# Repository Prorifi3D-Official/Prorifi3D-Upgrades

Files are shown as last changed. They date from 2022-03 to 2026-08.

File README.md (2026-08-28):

# Prorifi3D 
## Table of Content
### [For Slicer Profiles](https://github.com/Prorifi3D-Official/Prorifi3D-Upgrades/tree/main/Original%20i3%20series%20Upgrade%20Kits/Slicer%20Profile)
### [For Dual Belt Upgrade for Original i3 in Stage 1](https://github.com/Prorifi3D-Official/Prorifi3D-Upgrades/tree/main/Original%20i3%20series%20Upgrade%20Kits/Stage%201%20Upgrade/Dual%20Belt)
### [For Frame Upgrade for Original i3 in Stage 2](https://github.com/Prorifi3D-Official/Prorifi3D-Upgrades/tree/main/Original%20i3%20series%20Upgrade%20Kits/Stage%202%20Upgrade/Frame)
### [For Dual Belt Upgrade for Bear i3](https://github.com/Prorifi3D-Official/Prorifi3D-Upgrades/tree/main/Original%20i3%20series%20Upgrade%20Kits/Stage%201%20Upgrade/For%20Bear%20i3)
### [For MINI/MINI+ Upgrade](https://github.com/Prorifi3D-Official/Prorifi3D-Upgrades/tree/main/Original%20MINI%20series%20Upgrade%20Kits/MINI%20Upgrade/Dual%20Belt)
### [For the Printer Test Bench Guide](docs/Test_Bench_Guide.md)

## To find the latest Guide, visit our Knowledge Base:https://prorifi3d-knowledge-base.readthedocs.io/en/latest/

#### Our Official web site:https://prorifi3d.com/

#### Product page:https://prorifi3d.com/collections/upgrade-kit

#### Technical details about MRR:https://prorifi3d.com/pages/technical-details

#### Our YouTube Channel:https://www.youtube.com/channel/UCRQNWRVH8KuHBi94MY16joQ/featured

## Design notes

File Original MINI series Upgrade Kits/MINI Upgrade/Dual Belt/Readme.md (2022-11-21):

# Print Settings

### Recommended infill: >= 30%
### Recommended layer height: 0.2mm
### Recommended Material: PETG
### For other settings use: PrusaSlicer's default PETG 0.2mm presets
### For printed parts and multi-color parts, you can use the .3mf files to print them or as a reference, we recommend you use the water blue color first and then black. You can also use your own preferred color.

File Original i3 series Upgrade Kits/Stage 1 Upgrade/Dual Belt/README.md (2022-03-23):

# Print Settings

### Recommended infill: >= 30%
### Recommended layer hieght: 0.2mm
### Recommended Material: PETG
### For other settings use: PrusaSlicer's default PETG 0.2mm presets

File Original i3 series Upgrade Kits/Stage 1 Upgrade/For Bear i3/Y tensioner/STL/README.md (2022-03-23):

# Difference in Bear version:

### Y-Belt-Idler-A.stl -> Bear-y-idler-mount.stl
### Y-Belt-Idler-B.stl -> y_idler_tensioner.stl

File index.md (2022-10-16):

# HomePage
-------------------------------------

#This is the Prorifi3D Knowledge Base where you can find all technical details and information about our products and theory.

To get the Upgrade kits:

- [Upgrade Kit for Original i3 MK3/MK3S/MK3S+](https://prorifi3d.com/collections/upgrade-kit/products/kit)

- [Upgrade Kit for Original MINI/MINI+](https://prorifi3d.com/collections/upgrade-kit/products/mini)

- [Motor Development Kit](https://prorifi3d.com/collections/upgrade-kit/products/prorifi3d-motor-development-kit)

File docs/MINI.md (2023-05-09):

---
hide: navigation
---

# MINI:Motor Upgrades

## 1. Preparation and disassembly

### 1.0 Introduction

<span style="color:red"> **READ THE INSTRUCTION BEFORE UPGRADE!!** </span>  

- Prorifi3D Upgrade Kit for Original MINI/MINI+ is fully compatible with the Original i3 MINI series firmware and hardware.  

- Since you are upgrading an existing Original MINI or clone, you will have to replace X and Y motors, if you have experience in assembling Original MINI, that’s perfect! if not, don’t worry, follow this guide, and everything will be smooth and fine.  

- Disclaimer: We share these guides to make your experience as smooth as possible. However, you are responsible for your upgrade, assembly, and any damage you cause to your hardware.  

### 1.1 Check before Upgrade

Make sure you have the following tools and things available in the following 15 minutes:  

1. Your Original MINI 

2. 2.5mm, 2mm, and 1.5mm hex keys for disassembly, you can find one 1.5mm hex key in our accessory pack if you do not have one.  

3. A cutting tool for cutting zip ties  

4. Your Prorifi3D motor upgrade kit  

5. A small box for keeping the screws  

6. Printed parts for the new Dual belt Plus (From [Our GitHub](https://github.com/Prorifi3D-Official/Prorifi3D-Upgrades/tree/main/Original%20MINI%20series%20Upgrade%20Kits/MINI%20Upgrade)  Note that you will have to change the front and rear plate.

7. Open the Original Prusa MINI kit assembly Guide for reference([https://help.prusa3d.com/guide/1-introduction_203948](https://help.prusa3d.com/guide/1-introduction_203948))

- Make sure the filament is **unloaded** before the upgrade. You will have to turn the printer over during the process so the filament spool and spool holder need to be removed before the upgrade.

- Make sure your printer is **Not powered**, the nozzle and heated bed are fully cooled to room temperature! Otherwise, you may injure yourself!

- Make sure **both** ends of the power cord is unplugged to allow the printer to be placed sidewise.

## 2. Replace X and Y motors  

### 2.0 Disconnect the wires  

- Open the control box anddisconnect the X and Y motor wires.

### 2.1 Remove the X motors

- First you will have to lower the belt tension on the X axis before you replace the X motor. Follow [Step 30](https://help.prusa3d.com/guide/3-x-axis-extruder-assembly_199519#200635) to adjust the belt tension

- To uninstall X motor, please refer to the Original MINI guide from Step19 to [Step 26](https://help.prusa3d.com/guide/3-x-axis-extruder-assembly_199519#200484) 

### 2.2 Remove the Y motors

- First you will have to lower the belt tension on the Y axis before you replace the Y motor. Follow [Step 30](https://help.prusa3d.com/guide/2-yz-axis-assembly_196824#198050) in 2-yz-axis-assembly to adjust the belt tension and remove the current belt system.

- You will then need to remove the front plate by untightening the M5x20r screws. Then carefully take off the front plate and replace it with the new printed one.

- After you replace the front plate, do the same for the rear plate. Then remove the original Y motors on the rear plate.

### 2.3 Install Prorifi3D Motors

- Replace the original Y motor, the Prorifi3D motors has the same size and shape as the original ones, so it should be a direct replacement. Use the original screws.

- Collect and organize the Y motor wires. Make them the same as the original motor wires.

- Put the sleeve on the Prorifi3D X motor wire just like you did for the original motor. Use a zip tile to secure the sleeve position

- Install the Prorifi3D X motor to the original position, carefully put everything back as before. You can refer to the Original MINI guide from [Step19](https://help.prusa3d.com/guide/3-x-axis-extruder-assembly_199519#200201) to Step 26

- Adjust the tightness of the X and Y belt to be not too tight. We can fine-tune the belt tension later according to the print test. 

### 2.4 Reinstall the control box

- Reconnect the XY motor wire you took off previously. Put the cover back and tighten the screws.

- Be careful and make sure the X wire is not pressed or has been snapped by the Control box. 

## 3. Install the Dual Belt Plus 

### 3.1 Install the new MINI Y-Belt-Holder-A

- Insert two nylon nut as shown on MINI Y-Belt-Holder-A

alt alternative text 

- Install the new MINI Y-Belt-Holder-A with M3x12 screws, make sure you have the correct orientation.

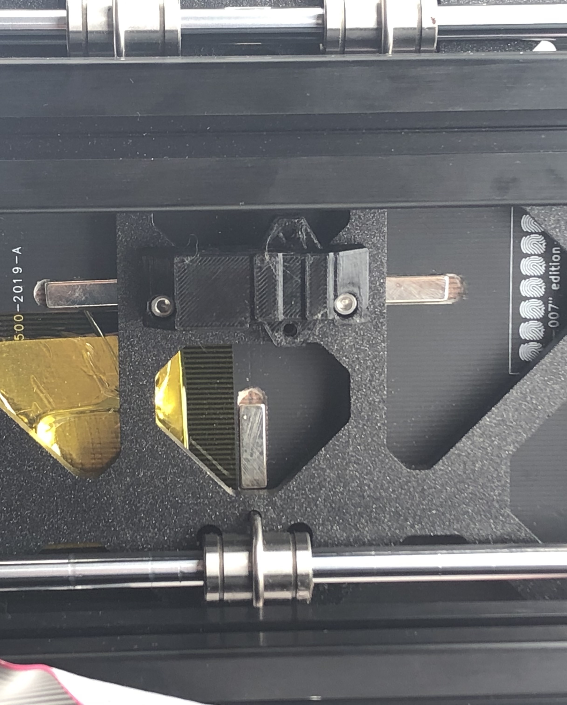
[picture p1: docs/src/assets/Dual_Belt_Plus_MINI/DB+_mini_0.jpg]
 

### 3.2 Assemble the Y tensioner

- Note that the new printed part is not symmetric!

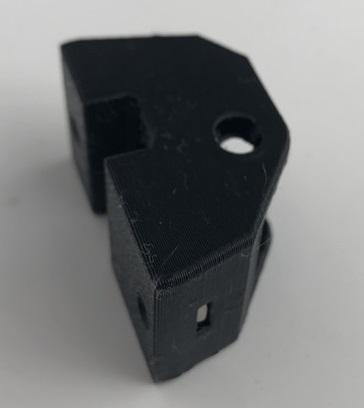
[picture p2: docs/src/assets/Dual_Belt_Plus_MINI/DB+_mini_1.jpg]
 alt alternative text

- Insert your hex key into the Y tensioner and place the bearings on the hex key one by one as shown. Guide the bearings and insert the hex key all the way through the Y tensioner. Note that you shall insert from the side which is not chamfered.

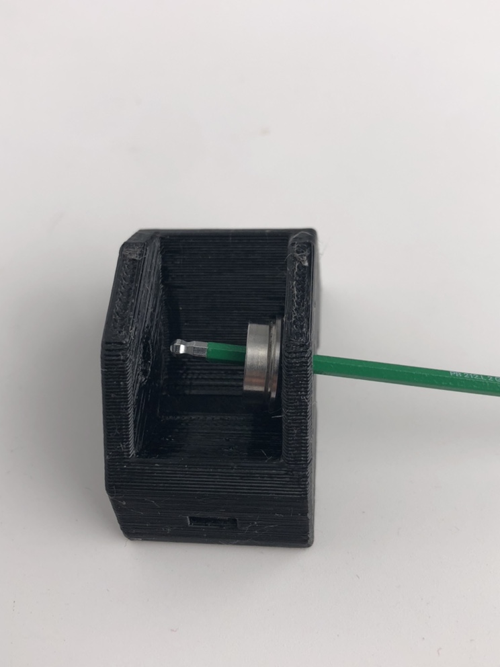
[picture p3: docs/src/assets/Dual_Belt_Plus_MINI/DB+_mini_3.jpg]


- The bearings should look as shown.

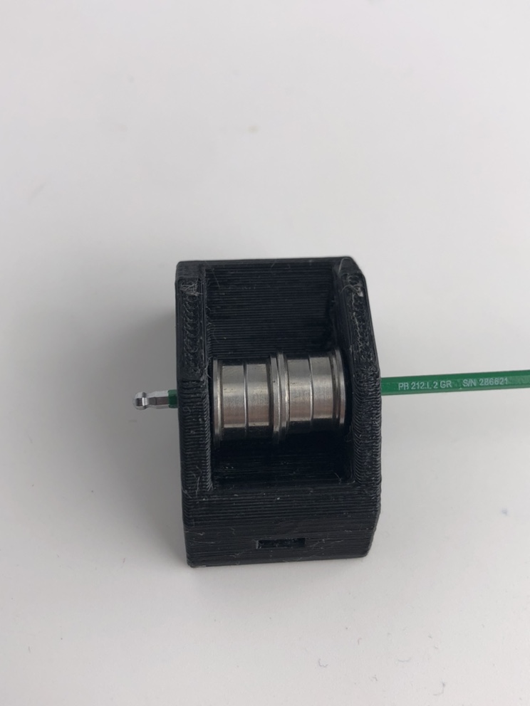
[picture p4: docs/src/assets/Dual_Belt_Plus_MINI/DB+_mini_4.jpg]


- Now, insert the pin from the **chamfered side** and use the pin to replace and push the hex key out of the bearings. 

alt alternative text

- Insert the pin all the way to the end. Use a 3mm hex key to assist and make sure the pin is at the end.

alt alternative text

- Insert the M3 square nuts into the Y tensioner. The installation location is the same as the original one. 

- The new Dual Belt Plus tensioner is complete!

- Pass the two belts through the Y tensioner as shown.

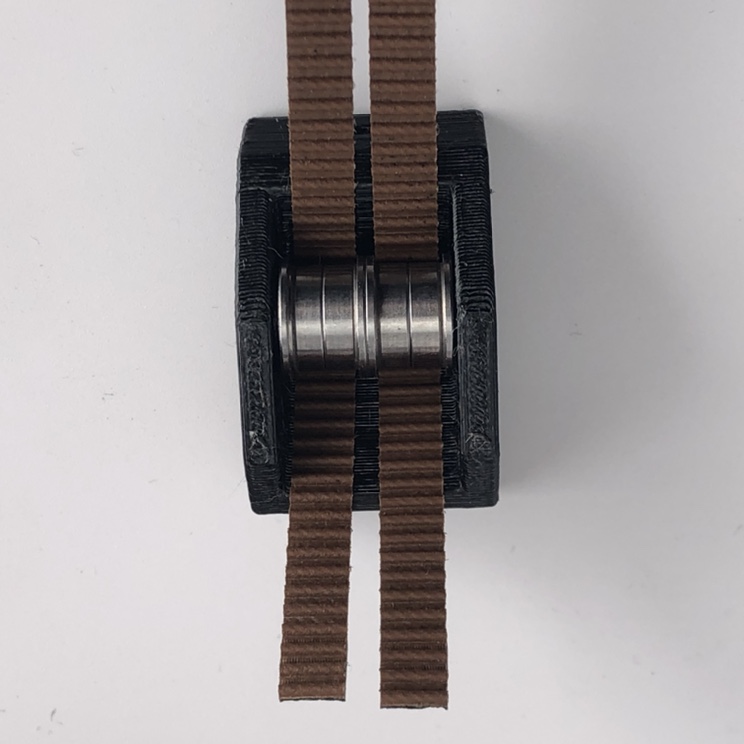
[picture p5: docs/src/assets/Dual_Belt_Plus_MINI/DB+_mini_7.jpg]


- Connect the timing belt as shown. Make sure the belts reach the end. Otherwise, the belt length will be different.

alt alternative text

- Replace the driving pulley with the new Dual Belt Plus version. Leaving only a small gap between the pulley and motors. 

- Pass the belt on the motors as shown.

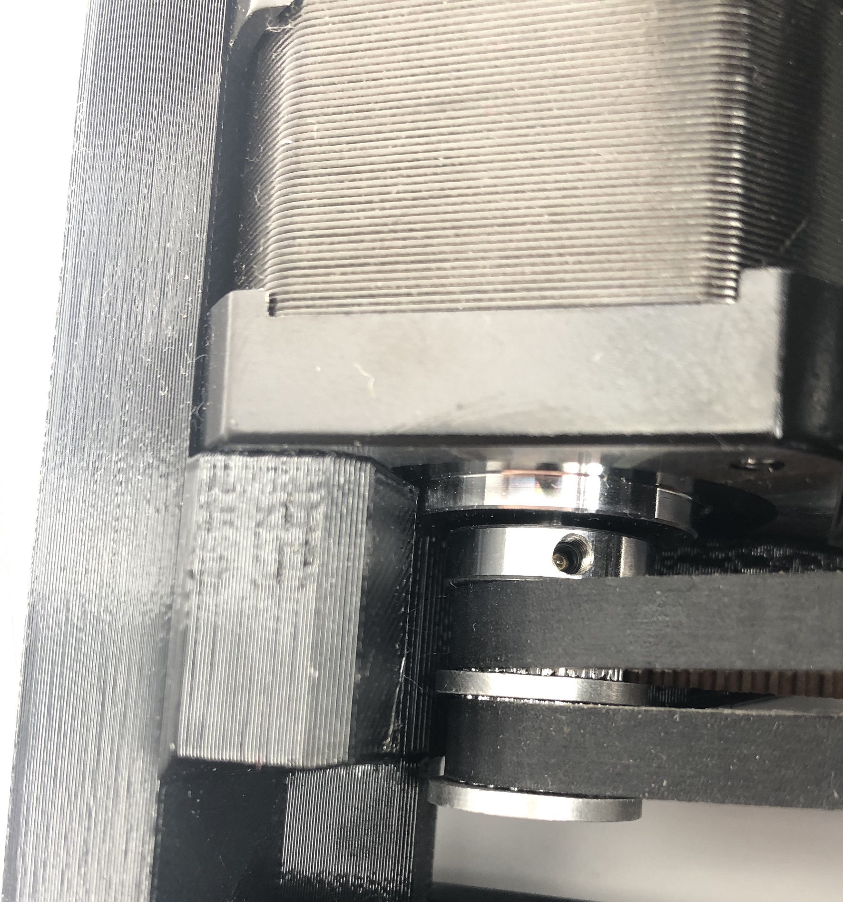
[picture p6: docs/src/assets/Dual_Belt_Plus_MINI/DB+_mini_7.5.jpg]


- Install the timing belt into the Y-Belt-Clip as shown. Put 2 M3x12 screws in advance.

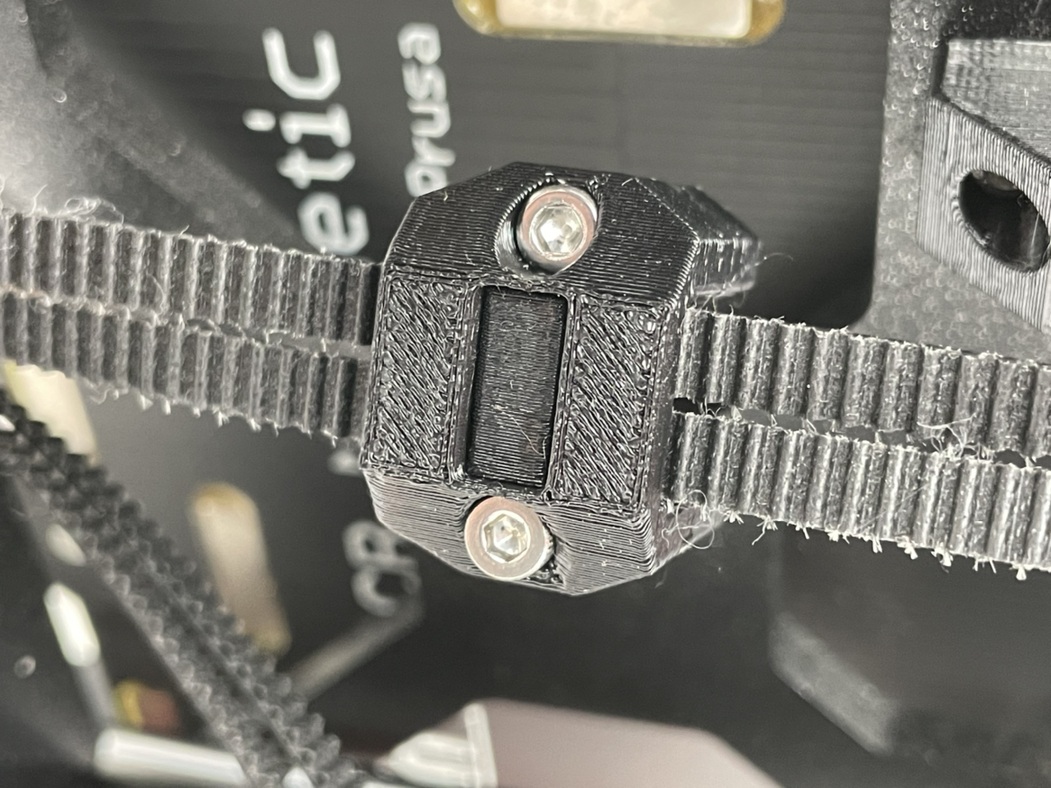
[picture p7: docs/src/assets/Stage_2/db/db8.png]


- Put Y Belt Clip into MINI Y Belt Holder B, the upper cover of the Y holder.

- Attach MINI Y Belt Holder B to MINI Y Belt Holder A. Make sure you turn the screws on both sides evenly in turn.

alt alternative text

- Install the Y tensioner with 2 M3*20 screws.

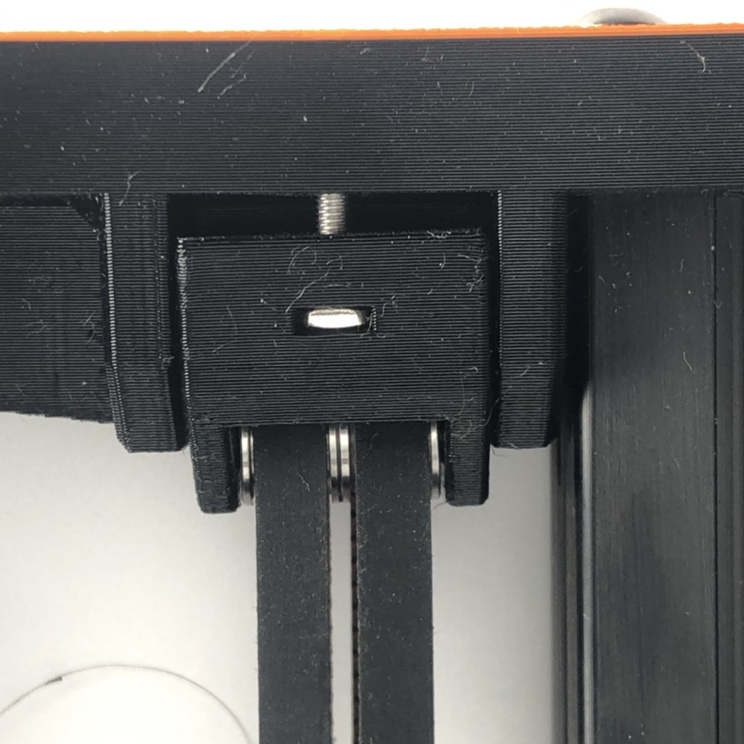
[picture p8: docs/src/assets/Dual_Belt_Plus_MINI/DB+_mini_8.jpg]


## 4. Belt tension adjust

- You can use phone apps to measure the belt vibration frequency.

- When measuring the belt frequency, push the heated bed all the way to the back (where the motor is). Slightly picking the lower belt in the middle as shown. You can use a hex key to assist. For the dual belt system you only need to pick one of the belts.

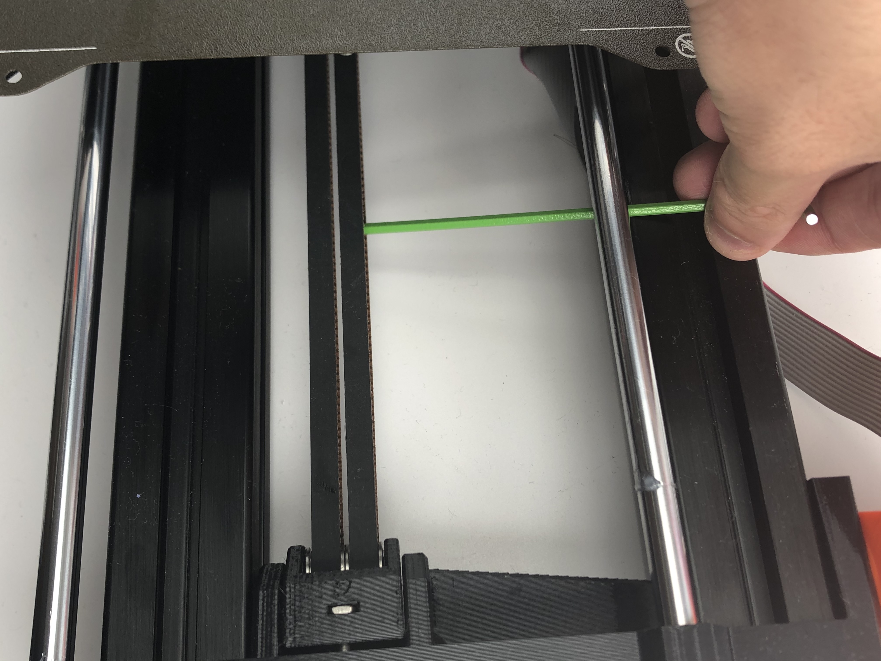
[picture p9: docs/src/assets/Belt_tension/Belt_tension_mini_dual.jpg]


- Adjust the belt tension to around 75Hz, move the Y axis and remeasure the belt frequency. Make sure the belt frequency is stable after your adjustment.

## 5. Performance boost 

### 5.1 Install the heat sinks

- To get an extra performance boost, you can install the heatsink first. This will lower the motor running temperature, allowing a larger current and better stability.

- Clean the mounting surface before you install the heatsinks. 

- For Y motors we recommend you install as shown:

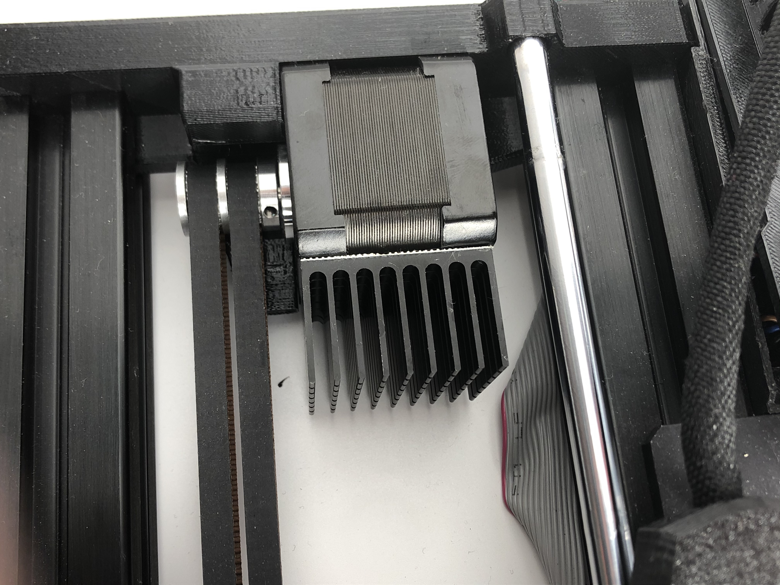
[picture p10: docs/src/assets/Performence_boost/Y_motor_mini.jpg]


- For X motors we recommend you install as shown:

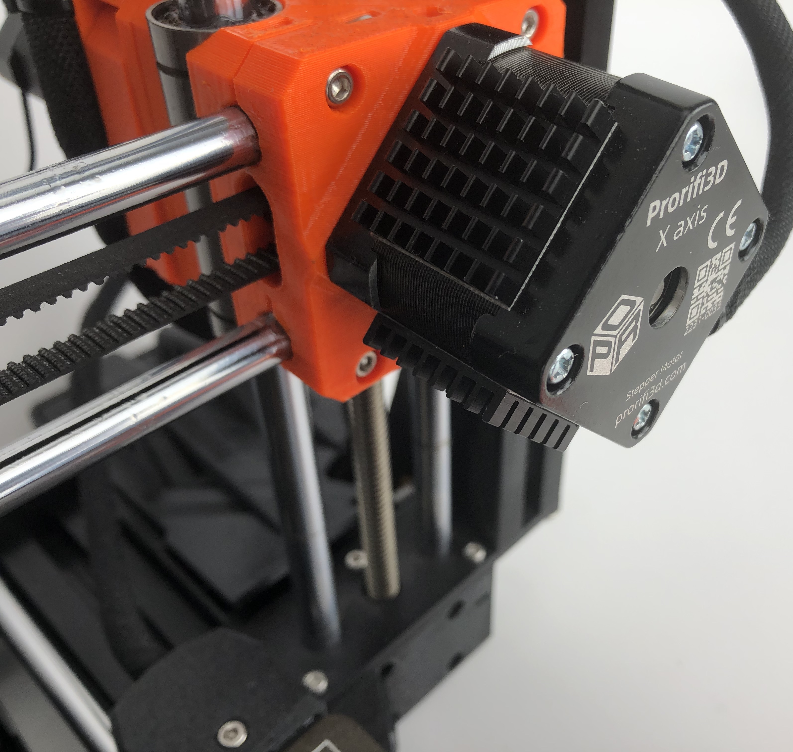
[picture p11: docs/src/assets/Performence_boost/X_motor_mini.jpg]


### 5.2 Changing the motor current

- You can change the current via G-code

- For the Original MINI, you can do this by adding custom Start Gcodes in the slicer software

- Change the RMS current of your XY motor by adding

```
M906 X520 Y520
```

- Change the steps per unit of Y axis by adding

```
M92 Y80
```

Note that you should put these extra code before doing mesh bed leveling!

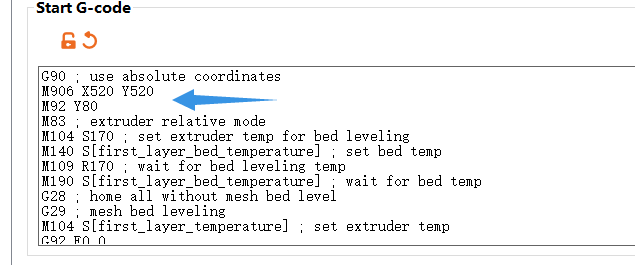
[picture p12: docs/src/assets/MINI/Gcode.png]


- Save this preset and use it as default, to change current **without** modifying the firmware, you will have to add these custom Gcodes in each print!

### 5.3 Test Print

- Print the [Test block](https://github.com/Prorifi3D-Official/Prorifi3D-Upgrades/tree/main/Test%20files) after you finishe all the necessary setup.

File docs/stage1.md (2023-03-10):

---
hide:
  - navigation
---
# Stage 1:Motor Upgrades

## 1. Preparation and disassembly

### 1.0 Introduction

<span style="color:red"> **READ THE INSTRUCTION BEFORE UPGRADE!!** </span>  

- Prorifi3D XY motor kit is fully compatible with the Original i3 Mk3 series firmware and hardware.  

- Since you are upgrading an existing Original Prusa or clone, you will have to replace X and Y motors, if you have experience in assembling Original i3, that’s perfect! if not, don’t worry, follow this guide, and everything will be smooth and fine.  

- Disclaimer: We share these guides to make your experience as smooth as possible. However, you are responsible for your upgrade, assembly, and any damage you cause to your hardware.  

### 1.1 Check before Upgrade

Make sure you have the following tools and things available in the following 15 minutes:  

1. Your Original i3  

2. 2.5mm, 2mm, and 1.5mm hex keys for disassembly, you can find one 1.5mm hex key in our accessory pack if you do not have one.  

3. A cutting tool for cutting zip ties  

4. Your Prorifi3D motor upgrade kit  

5. A small box for keeping the screws  

6. Printed parts for the new Dual belt (From [Our GitHub](https://github.com/Prorifi3D-Official/Prorifi3D-Upgrades))  

7. Open the Original Prusa i3 MK3S kit assembly Guide for reference([https://help.prusa3d.com/en/guide/1-introduction_24976](https://help.prusa3d.com/en/guide/1-introduction_24976))

8. Make sure you have a flat surface such as a polished marble top, or a big ceramic tile. This surface will be your base level.  

9. **If you have the Original i3 Mk3/s we suggest you upgrade the Y belt holder and tensioner to the Mk3s+ version which allows you better adjust the belt tension **

- Make sure the filament is **unloaded** before the upgrade. You will have to turn the printer over during the process so the filament spool and spool holder need to be removed before the upgrade.

- Make sure your printer is **Not powered**, the nozzle and heated bed are fully cooled to room temperature! Otherwise, you may injure yourself!

- Make sure **both** ends of the power cord is unplugged to allow the printer to be placed sidewise.

## 2. Replace X and Y motors  

### 2.0 Disconnect the wires  

- Unscrew the M3*40 screws on the Einsy-door so you can open it.  

- keep the screw in the small box so you will not lose it.  

- Now, carefully unplug the X and Y motor wires from the mainboard and make sure other wires stay connected.  

- The control box is fixed by two screws located inside the box. You can refer to steps 11-13 in the Electronics assembly in the Original Prusa i3 MK3S kit assembly ([https://help.prusa3d.com/en/guide/8-electronics-assembly_34416](https://help.prusa3d.com/en/guide/8-electronics-assembly_34416)). Use a 2.5mm Allen key to slightly untighten both screws, Do not remove them completely.  

- Carefully push and slide the Einsy base to take it off. Now you can get the X motor wire out of the base completely.  

- Turn the printer so you can reach the bottom of it, and make sure it is sitting still and safe. There are a few zip tiles you need to cut before removing the Y motor. Cut the zips and take the Y motor wires out and keep the others.

<span style="color:red"> Be careful with the wires when you cut the zip tile </span>  

### 2.1 Remove the X motors

- Untighten the screws on the driving pulley to make sure you can remove the pulley from the motor later. There are two screws 90 degrees apart on the pulley.

- Slowly push the E axis away from the X motor side. Use the finger to snap the belt. You should feel some force which means the belt is tight. Now slowly untighten the tension screw and the three screws that fix the X motor with a 2.5mm Allen key until you feel no force between your fingers.

- Now use your hand to assist and hold the X motor so it will not suddenly fall off. Use a 2.5mm Allen key to remove the three screw that holds the X motor. Do not keep the screws.

- Take off the X motor and remove the pulley from the motor.

- Put the motor aside. keep the driving pulley in the box for later use. Leave the belt hanging for now.  

- Cut the zip tile on the sleeve, and remove and keep the sleeve for later use.

### 2.2 Remove the Y motors

- First, turn the printer sidewise with X motors on top and make sure nothing is damaged.

- Slightly release the two screws on the Y belt holder to untighten the Y belt. Keep the screws in the box for later use. Take the Y belt off the driving pulley.

- As you did on the X motor, untighten these set screws on the pulley(both of them), and remove the Y driving pulley.

- Remove the three screws on the Y motor mount and take off the Y motor, put it aside. Do not keep the screws.

### 2.3 Install Prorifi3D Motors

- Install the Prorifi3D Y-motor in the place of the original Y motor. Use M3x8mm screws.

- Collect and organize the Y motor wires. Make them the same as the original motor wires and zip them to secure the wiring.

- Put the sleeve on the Prorifi3D X motor wire just like you did for the original motor. Use a zip tile to secure the sleeve position

- Install the Prorifi3D X motor in the original position, make sure you use M3x16mm screws.

- Reinstall the X driving pulley

- Adjust the position of the X driving pulley, make sure the belt does not touch the edge of the pulley when moving.

- Adjust the tightness of the X belt. We can fine-tune the belt tension later according to the print test. This is because over-tightening the belt can make MRR worse, However, untightening too much will result in the polygon effect which causes the 2mm VFA. So adjusting the belt to an ideal tension is necessary to improve the print quality.

### 2.4 Reinstall the control box

- Open the Einsy door. Reconnect the XY motor wire you took off previously. Close the Einsy door. Take and tighten the M3x40mm screw to close the Einsy door when you finish the electronics.

- Put the Control box back to its original place and tighten the screws to secure the control box. Be careful and make sure the X wire is not pressed or has been snapped by the Control box. The wire should come through the side hole in the control box.

## 3. Belt tension adjust

- First set your belt to the lowest tension. You can use phone apps to determine the vibration frequency of your belt. For the Original i3 Mk3 series the minimum value should be about 54Hz.

- You can use phone apps to measure the belt vibration frequency.

- When measuring the belt frequency, push the heated bed all the way to the back (where the motor is). Slightly picking the lower belt in the middle as shown. You can use a hex key to assist.

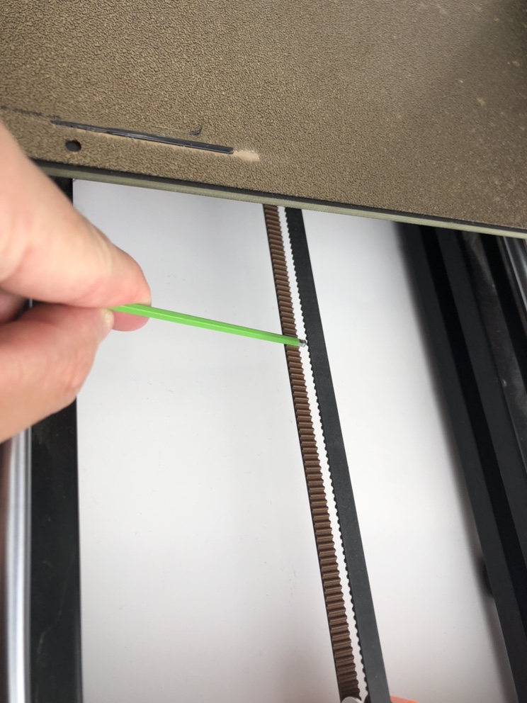
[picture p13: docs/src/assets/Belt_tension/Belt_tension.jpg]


- The recommended tension for Original i3 with Prorifi3D motors is around <span style="color:red">84Hz for the Y axis</span> and <span style="color:blue">57Hz for the X axis</span>.

- Print the [Test block](https://github.com/Prorifi3D-Official/Prorifi3D-Upgrades/tree/main/Test%20files) to check your result.

- For more about VFA(MRR) please check [here](https://prorifi3d-knowledge-base.readthedocs.io/en/latest/How_to_solve_MRR/)

## 4. Performance boost (optional) 

### 4.1 Install the heat sinks

- To get an extra performance boost, you can install the heatsink first. This will lower the motor running temperature, allowing a larger current and better stability.

- For Y motors we recommend you install as shown:

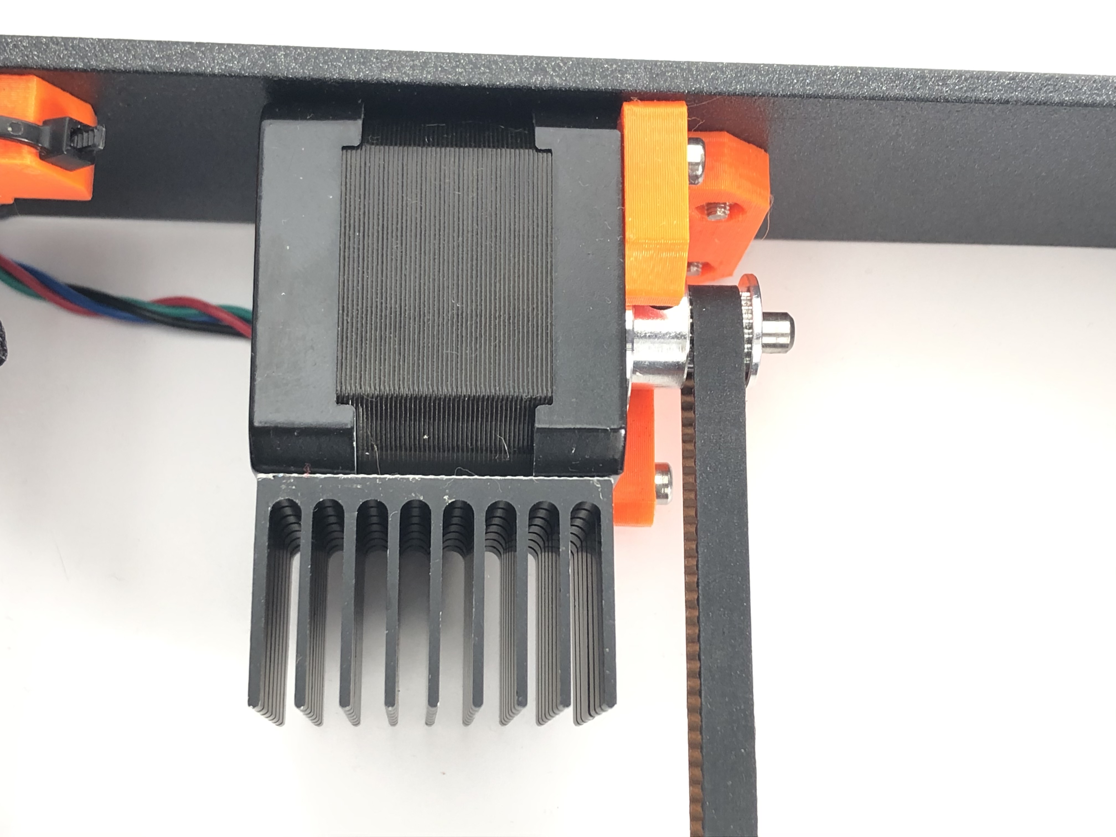
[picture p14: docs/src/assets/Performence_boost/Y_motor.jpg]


- For X motors we recommend you install as shown:

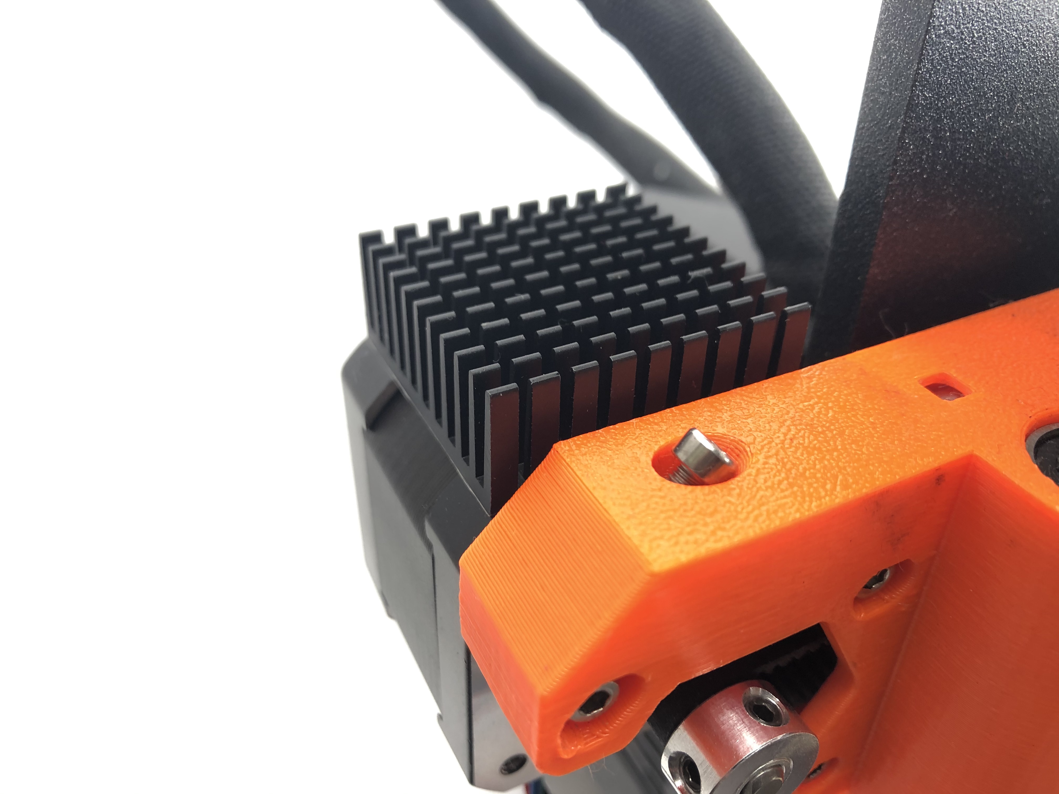
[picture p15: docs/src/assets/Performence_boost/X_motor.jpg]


### 4.2 Changing the motor current

- You can change the current via Gcode

- First, connect your printer using a USB cable

- Use Pronterface to connect your printer

- Change the RMS current of your XY motor using

```
M907 X520 Y520
```

- Save the settings by typing

```
M500
```

## 5. Remove and replace the E & Z motors (additional)

- For removing and installing Z motors please refer to :[https://help.prusa3d.com/en/guide/4-z-axis-assembly_168629](https://help.prusa3d.com/en/guide/4-z-axis-assembly_168629 )

- Note that in Step 4 Z-axis: assembling the motors, use M3x8 instead of M3x10 

- For removing and installing Z motors please refer to :[https://help.prusa3d.com/en/guide/5-e-axis-assembly_169235](https://help.prusa3d.com/en/guide/5-e-axis-assembly_169235)

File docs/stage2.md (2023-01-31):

---
hide:
  - navigation
---
# Stage 2:Frame Upgrades & Dual Belt Plus

## 1. Preparation

### 1.0 Introduction

<span style="color:red"> **READ THE INSTRUCTION BEFORE UPGRADE!!** </span>  

- Since you are upgrading an existing Original Prusa or clone, if you have experience in assembling Original i3, that’s perfect! if not, don’t worry, follow this guide, everything will be smooth and fine. Also feel free to contact us.

- Disclaimer: We share these guides to make your experience as smooth as possible. However, you are responsible for your upgrade, assembly, and any damage you cause to your hardware.

### 1.1 Check before Upgrade

Make sure you have the following tools and things available：

1. Your Original i3 

2. 4mm, 3mm, 2.5mm, 2mm, and 1.5mm hex keys for disassembly, you can find one 1.5mm hex key in our accessory pack if you do not have one.

3. A cutting tool for cutting zip ties 

4. Your Prorifi3D upgrade kit 

5. A box for keeping the screws 

6. Printed parts from [our GitHub](https://github.com/Prorifi3D-Official/Prorifi3D-Upgrades)

7. Open the Original Prusa i3 MK3S kit assembly Guide for reference([https://help.prusa3d.com/en/guide/1-introduction_24976](https://help.prusa3d.com/en/guide/1-introduction_24976))

8. Make sure you have a **flat surface** such as a polished marble top, or a big ceramic tile. This surface will be your base level.

- Make sure the filament is **unloaded** before the upgrade. You will have to turn the printer over during the process so the filament spool and spool holder need to be removed before the upgrade.

- Make sure your printer is **Not powered**, the nozzle and heated bed are fully cooled to room temperature! Otherwise, you may injure yourself!

- Make sure **both** ends of the power cord is unplugged to allow the printer to be placed sidewise.

- For disassembling the Original i3 you can refer to this guide:[https://guides.bear-lab.com/Guide/02.+Preflight+check+and+disassembly/42?lang=en](https://guides.bear-lab.com/Guide/02.+Preflight+check+and+disassembly/42?lang=en)

- For the Dual Belt Plus please use PETG with at least 30% infill. The printed part should orientate as shown. Note that this part can be printed without support. 

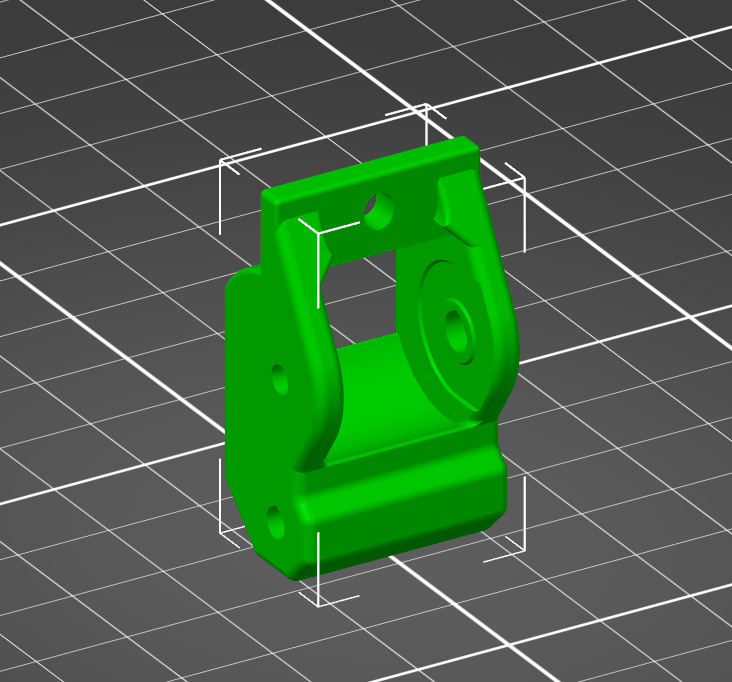
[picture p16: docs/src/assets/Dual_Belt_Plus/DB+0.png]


## 2. Assemble the Main Frame

### 2.0 Check before the assembly

- Make sure you have the following parts: All the aluminum profiles, your Hex Keys, Accessory Pack 1

- A measuring tool for screws, you can find the STL file [here](https://github.com/Prorifi3D-Official/Prorifi3D-Upgrades/tree/main/Tools) (If you know how to measure the screws then use a ruler instead)

- Make sure you have a flat and big enough surface such as a polished marble top, or a big ceramic tile. This surface must be able to fit the longest Aluminum profile in any direction. Clean the surface to remove any dust or small debris.

- Check the inside of the two longest beams, there should be two plastic plugs been pre-installed at both ends. If not, please contact us.

### 2.1 Assemble the gantry

- Take the left and right vertical beams (the longest ones).

- Check the beam and make sure you have the correct orientation. The <span style="color:green">side with chamfers</span> should face downward, against the flat surface. The side indicated by the <span style="color:blue">blue arrow</span> should face outward.

alt alternative text

- Take the short <span style="color:blue">4040 profile</span> and place them as shown. The side with Chamfers needs to be facing down, against the flat surface.

- Use one <span style="color:green">2040 beam</span> as the jig, place it as shown

- Note the <span style="color:red">orientation!</span> The 4040 should on the side with 3 screw holes. 

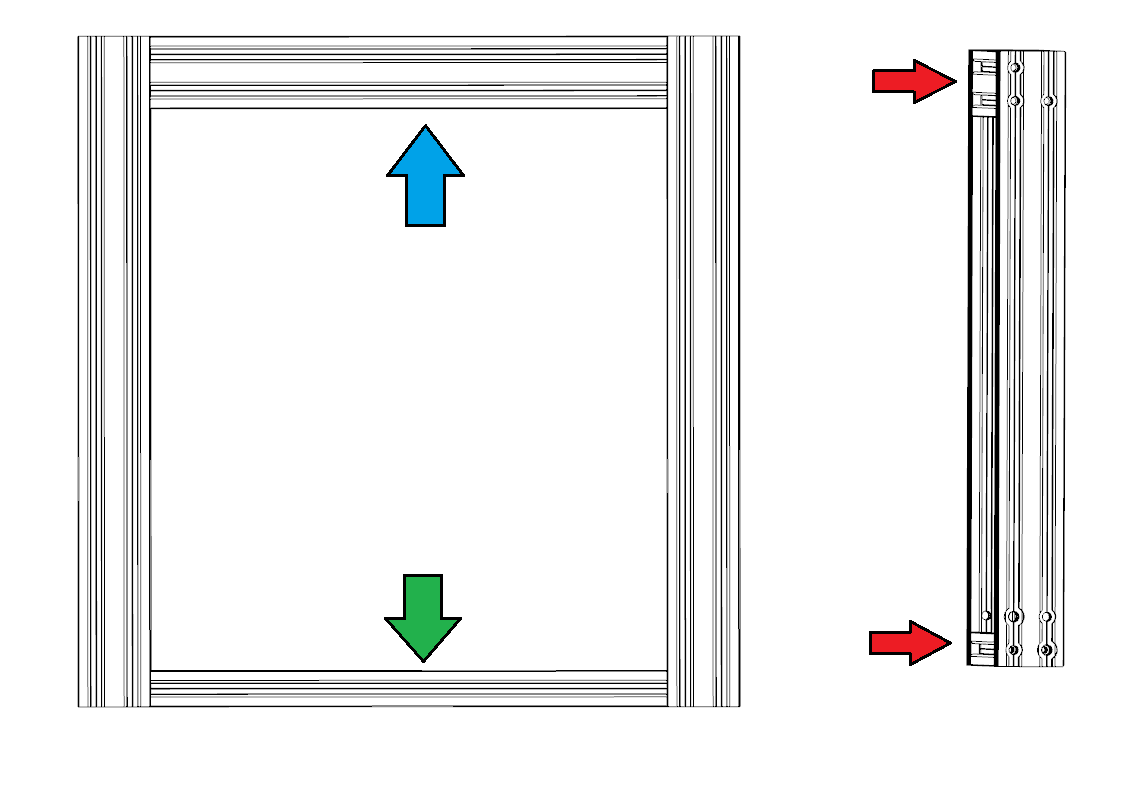
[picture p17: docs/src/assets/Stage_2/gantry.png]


- Use M5x45 screws from Accessory Pack 1 and tighten the screws as shown on both sides. Note the <span style="color:green">Upper one</span> is for adjustments. Do not fully tighten it.

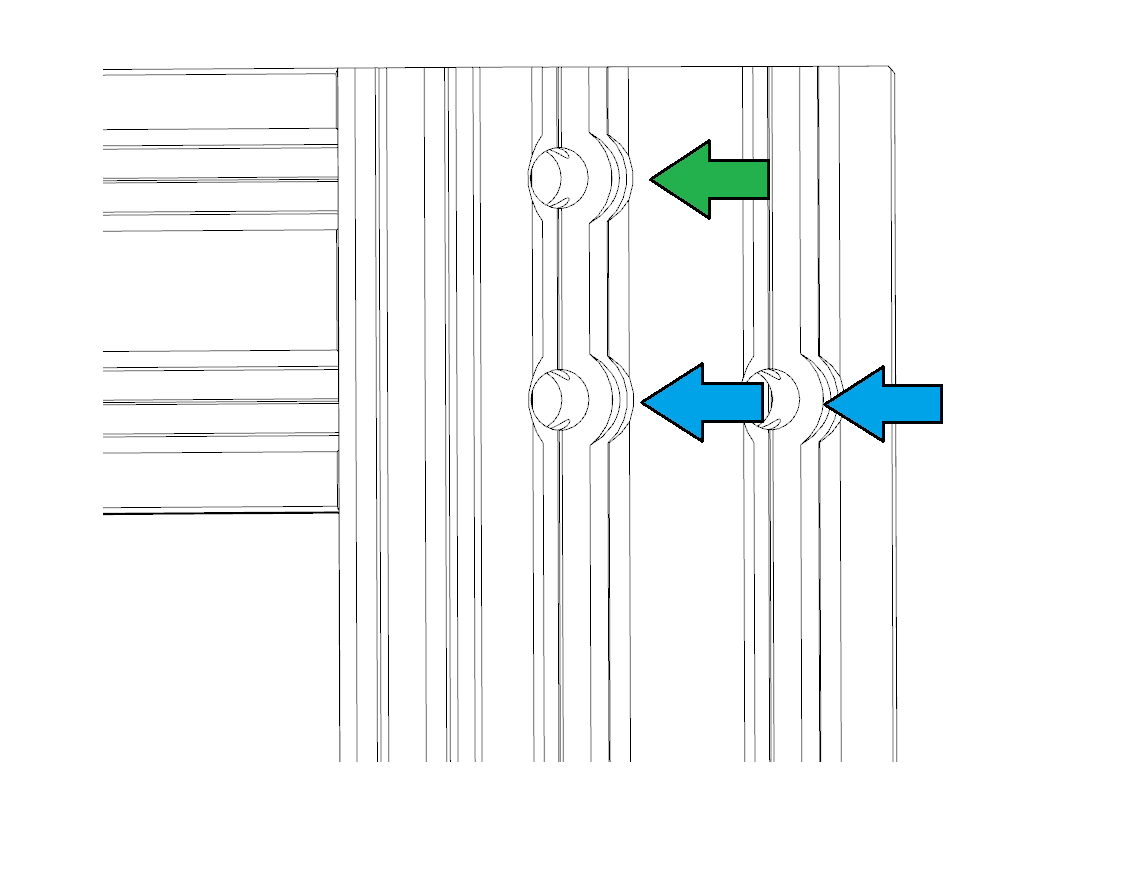
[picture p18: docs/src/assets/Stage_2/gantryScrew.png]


- Adjust the <span style="color:green">upper screws</span> on **both** sides evenly to make sure the 2040 beam used as a jig can just about move freely up and down at the open end of the gantry

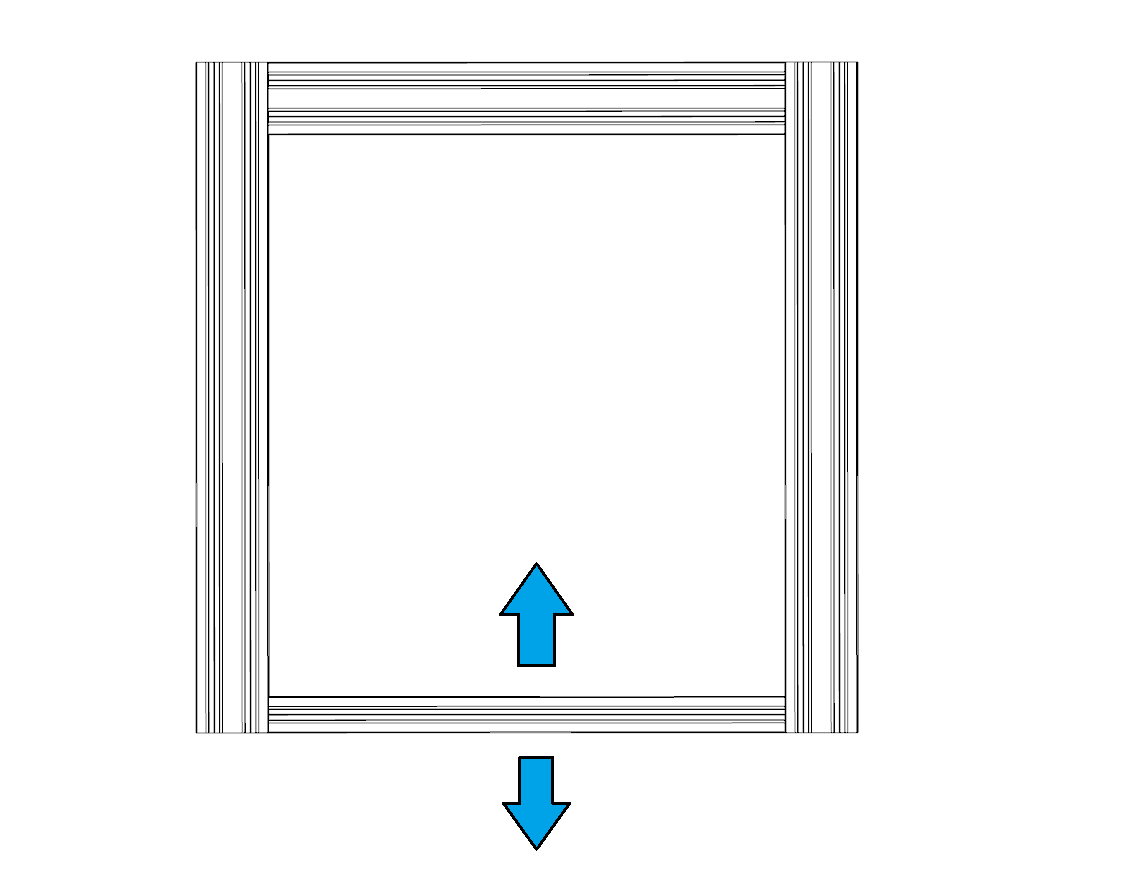
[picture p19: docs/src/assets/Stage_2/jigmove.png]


### 2.2 Assemble the base

- Take the rest 4040 and 2040 profiles

- Check the beam and make sure you have the correct orientation. The side with chamfers needs to be facing down, against the flat surface. The sinkholes should face out as the green arrow shows. The front and rear 2040 profiles are the same, just make sure you have the correct side facing out and <span style="color:green">chamfered side</span> facing down.

- Place them as shown. Note that for the 4040 profiles, be careful with the position of the <span style="color:blue">screw holes</span>. Make sure you have the correct relative position!

alt alternative text

- Insert 2 T-Nut in the bottom <span style="color:blue">inner slot</span> of the 4040 profile, do this for both left and right 4040 profiles. These will be used to fix the footpad later.

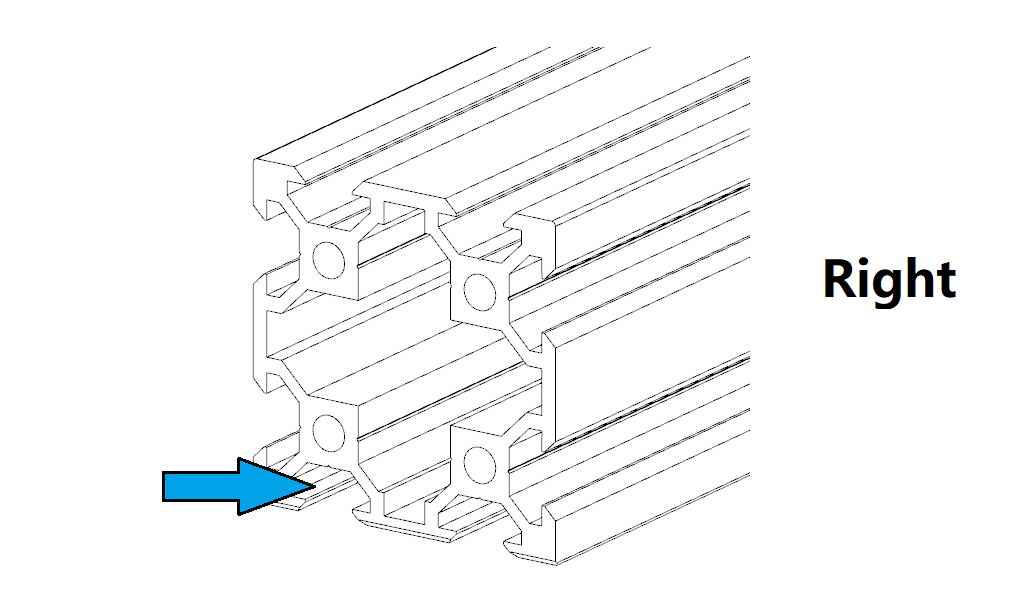
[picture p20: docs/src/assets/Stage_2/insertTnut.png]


- Insert 6 T-nut in the <span style="color:blue">upper slot</span> of the inner side of the rear 2040 profile and insert 1 in the <span style="color:green">lower slot</span>.

alt alternative text

- Insert 6 T-nut in the <span style="color:blue">upper slot</span> of the inner side of the front 2040 profile and insert 2 in the <span style="color:green">lower slot</span>.

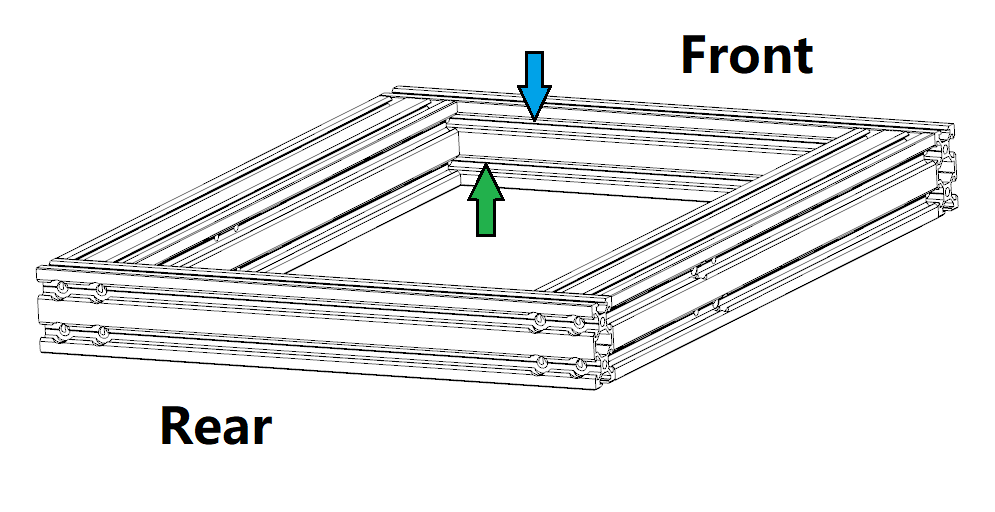
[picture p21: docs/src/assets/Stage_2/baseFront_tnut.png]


- Double-check if you insert the correct amount of T-nuts and they are in the correct position!

- Now we can build the base. Make sure both sides are aligned. You can use a piece of a flat surface, such as the jigs you printed to help you align these beams.

- Take the M5x25 screws, you need 16 of them. Use them to fix the front and rear profiles. Make sure you tighten them in a diagonal order. When tightening the screws, do not fully tighten a screw before you tighten the next one. Screw them in evenly. <span style="color:red">Make sure all the aluminum profiles are not moved or have gaps with the flat surface</span>. This is very important!

- Turn the base over and install the footpad. Use M5x10 button head screws to fix them. Turn the base back and if it shakes, adjust the screws on footpads until they are all in the same plane.

### 2.3 Assemble the mainframe

- Check if the T-nuts are correctly inserted again before this part!

- Make sure the reference surface (the side with chamfers) for the base is facing downwards, against the flat surface. At this point, the reference surface should be flat and directly touching the flat surface with no gaps between.

- Take the gantry, make sure you have the correct orientation!

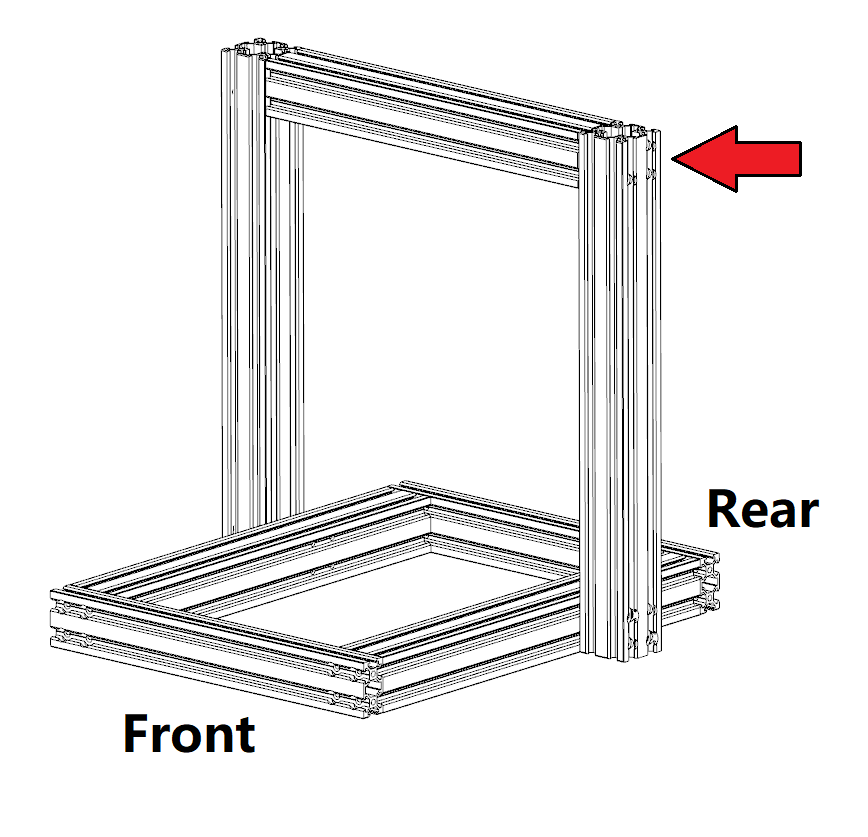
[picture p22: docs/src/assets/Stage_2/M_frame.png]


- As you can see, on the lower end of the gantry there are 4 screw holes on each side, and they are shaped differently. Viewed from one side, the upper left one is the pinhole. And the 4 screw holes match the holes on the base.

- Carefully match the gantry and the base. Take a shoulder screw(the one with steel case) and insert it into the <span style="color:blue">upper left</span> pinhole to the bottom, slightly tighten this screw. It is ok if you feel some force or resistance when inserting this screw.

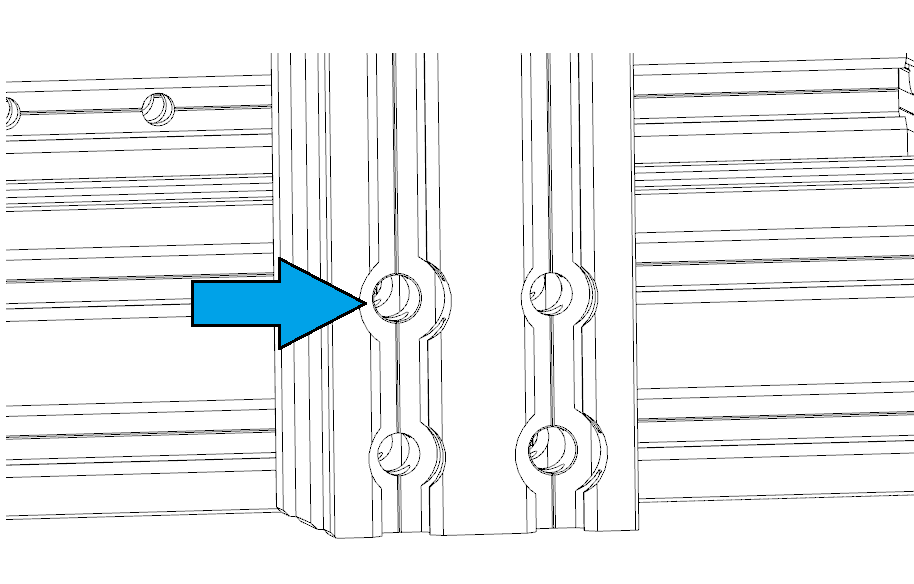
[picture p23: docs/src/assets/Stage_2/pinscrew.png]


- Do the same for the other side. Now the position of the base and gantry are locked and make sure the gantry stands against the flat surface, there should be no gap between the gantry end and the surface, or the base and surface.

- Now the gantry is perpendicular to the base, take the M5x70 screw (the longest normal screw) and install them to the lower right hole on each side. 

alt alternative text

- Take 4 M5x50 screws to fill the rest screw holes. 

- Now you should tighten the screws evenly in a diagonal order. Note that the shoulder screw is for positioning thus cannot be tightened much. Make sure the rest M5 screws are fully tightened!

- The main frame is now finished, if perfectly assembled you should see no gap between the base and the flat surface you have. And if you shake the gantry, there should be absolutely no relative movement between the gantry and the base.

### 2.4 Prepare the next phase

- At this point, we just finished the main frame and are moving to the next phase. It is time to take the **accessory pack 2**. There are many screws in it so be careful. You will find screws with the socket head cap, the button head cap, the flat head cap, and the countersunk screws. You can use the [measuring tool](https://github.com/Prorifi3D-Official/Prorifi3D-Upgrades/tree/main/Tools) to help you classify the screw.

- If you found anything confusing or are not sure, you can always reach out to us!

## 3. Disassemble your Original i3

### 3.1 Modifications before disassembly

- Before you do the disassemble. Please change the X motor first as we will reuse the entire X-axis and E-axis later.

- If you would like to replace the E motor as well, please refer to the section: [5. E-axis assembly](https://help.prusa3d.com/guide/5-e-axis-assembly_28536) in the offical guide to rebuild the E axis with the Prorifi3D E motor.

### 3.2 Replace the X motor on the X-axis

- Untighten the screws on the driving pulley to make sure you can remove the pulley from the motor later. There are two screws 90 degrees apart on the pulley.

- Slowly push the E axis away from the X motor side. Use the finger to snap the belt. You should feel some force which means the belt is tight. Now slowly untighten the tension screw and the three screws that fix the X motor with a 2.5mm Allen key until you feel no force between your fingers.

- Now use your hand to assist and hold the X motor so it will not suddenly fall off. Use a 2.5mm Allen key to remove the three screw that holds the X motor. Do not keep the screws.

- Take off the X motor and remove the pulley from the motor.

- Put the motor aside. keep the driving pulley in the box for later use. Leave the belt hanging for now.  

- Cut the zip tile on the sleeve, and remove and keep the sleeve for later use.

- Put the sleeve on the Prorifi3D X motor wire just like you did for the original motor. Use a zip tile to secure the sleeve position

- Install the Prorifi3D X motor in the original position, make sure you use M3x16mm screws.

- Reinstall the X driving pulley

- Adjust the position of the X driving pulley, make sure the belt does not touch the edge of the pulley when moving.

- Adjust the tightness of the X belt. We can fine-tune the belt tension later according to the print test. 

### 3.3 Disassemble

- For disassembling the Original i3 you can refer to the bear guide:[https://guides.bear-lab.com/Guide/02.+Preflight+check+and+disassembly/42?lang=en](https://guides.bear-lab.com/Guide/02.+Preflight+check+and+disassembly/42?lang=en)

- The Bear upgrade is also a decent frame upgrade and we took some inspiration from it despite using a completely different approach and mechanical design principles.

- The part you need to keep and reuse later:

	- The entire X-axis and E-axis together

	- The PSU

	- The Y-axis, including the rod, but without the belt system

	- The Control board and the control box

	- The Z rods

	- The Z motors, if you did not get the full upgrade kit

	- The LCD

	- The Control Box

## 4. Build the Machine

### 4.0 Screws and nuts

alt alternative text

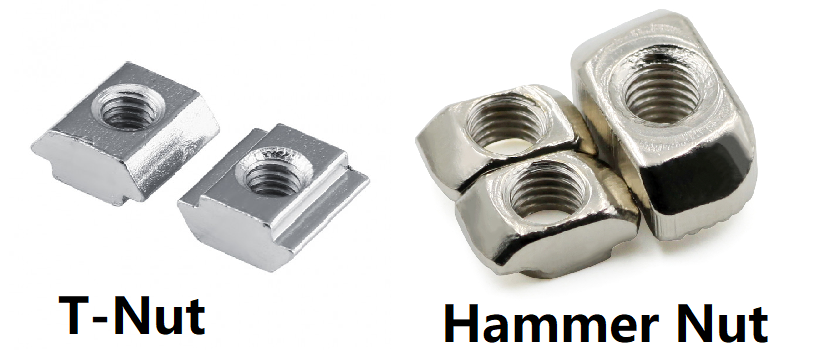
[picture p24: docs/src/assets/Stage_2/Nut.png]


- Let us start with the Z-axis first. Take the Z rod from you recycled from your Original i3 and the left and right Z Motor Mounts

- First, put the <span style="color:green">Z motors</span> into the motor mounts firmly and install the <span style="color:blue">steel rods</span> first. Z motor here is used as a jig.

alt alternative text

- Then, remove the Z motors. Make sure the rod stays firmly on the motor mounts and the <span style="color:red">bottom end</span> of the rod does not stick out the printed parts.

- Insert <span style="color:blue">flat head M5x10</span> on the Z motor mounts, then hook T nut on the screws.

alt alternative text

- Slide the Z motor mount into the slots from the top. Make sure you have the correct orientation.

alt alternative text

- Press the printed part sideways against the profile and slide them to the position where printed parts are just about to touch the base, as shown in the picture below.

alt alternative text

- Tighten the screws to make sure it does not move freely. Do this for both left and right z motor mount.

- Now carefully reinstall the X-axis, be careful with the linear bearings! You should lower the X-axis evenly. Do not proceed if you feel too much resistance or force, the linear bearings are <span style="color:red">**very very easy to break!**</span>

- Take the Left and right Z top, insert <span style="color:blue">M5x10 flat head</span> at the front and <span style="color:green">M5x12 flat head</span> at sides. Hook hammer nuts on the screws and then install the Z top. The Z steel rods should be in the <span style="color:red">slots</span> on the Z top and will not fall out. Then tighten all the M5 flat head screws.

alt alternative text

Use <span style="color:blue">M4x5 set screws</span> to fix the back end of the Z top.

alt alternative text

- Do this for both left and right sides.

## 4.2 Z motors

- Now it is time to install the Z motors. Make sure you have the correct Z motors. The one with shorter wires should be closer to the control box! (which is at left when viewing from the front)

- Put the motors in from the bottom. Rotated the leading screw evenly to allow the motors to be in position. The printed parts have slots for wires to pass through. Make sure no wires are clamped or twisted.

alt alternative text

Use <span style="color:blue">M3x12 screws</span> to fix the motors. You should tighten the screws evenly in a diagonal order.

alt alternative text

Install the Bottom cover at the end of the gantry beams and fix them with <span style="color:blue">M4x5 set screws</span> on both left and right sides.

alt alternative text

- Collect the wires and proceed to the next step

### 4.3 Y-axis

- Take the 4 Y rod holder, insert the square nut and pre-install the <span style="color:blue">M3x12 set screws</span> (the longer one) Make sure you have the correct orientation of the set screws

- Install Y rod holder, be careful with the orientation. 

alt alternative text

- Use the positioning jig and hex key to slide the T nut to the correct position. Place the T-nut to where the screws holes hould be. Do this for all 4 positions.

alt alternative text

- Now carefully put the entire Y-axis back from the top. Slide Y carriage to make sure the movement is smooth.

- Now use the M5x10 button head to fix the left 2 <span style="color:blue">Y rod holders</span>. If you feel the T nut is not in position, try using the hex key to help align the T-nuts first.

alt alternative text

- Slide the Y carriage back and forth to make sure the right Y rod is in the ideal position.

alt alternative text

- Tighten the screws of the 2 right <span style="color:blue">Y rod holders</span>

alt alternative text

- Slide the Y carriage back and forth and check if it moves smoothly. If not, untighten the screws on the right 2 Y rod holder and repeat the previous 2 steps to make sure the Y rods are parallel to each other.

- Now take the Y motor mount and Y motor, first install the Y motor to motor mounts use M3x14 screws, make sure the wire comes out from the bottom

- Now insert 3 socket cap M5x10 screws into the Y motor mount.

- Adjust the pre-inserted T-nuts to an ideal position, hook the T-nuts with the M5 screws on your Y motor mount.

- Slightly tighten the screw to make sure the printed parts do not fall off, make sure it can still move freely

- Use the <span style="color:green">jig</span> as shown to position the Y motor mount.

- Press the <span style="color:blue">printed part</span> against the base and tighten the screws.

alt alternative text

- Take out the  Y-Belt-Idler-A, Insert one nylon nut as shown

alt alternative text

- Insert another nylon nut here

alt alternative text

- Insert 4 socket cap M5x10 screws. Hook the T-nut with the screws and then use the <span style="color:green">motor jig</span> to position the idler.

- Press the <span style="color:blue">printed part</span> against the base to make it parallel to the reference surface and tighten the screws.

alt alternative text

### 4.4 The control box

- Take the Electronics-Cover-Holder-C, insert 2 M5x10 button cap screws and hook the hammer nut on the screws. Install them at the back of the left gantry beam. Note the <span style="color:blue">printed part surface</span> should be at the same level as the base.

alt alternative text

- You can reuse most of your old control box. However, there are some additional parts.

- Insert the <span style="color:blue">hex nut</span> into these positions and change the screws to M3x15 at these positions.

- Insert one <span style="color:green">flat cap M5x8 screw</span>, then hook 1 hammer nut on the M5x8 screw.

alt alternative text

- The final control box should look like this.

alt alternative text

### 4.5 PSU

- Take the PSU and PSU-Holders, Install the holder on PSU with <span style="color:blue">M4x8 countersunk screws</span>

alt alternative text

- Install <span style="color:blue">M3x6 screws</span> here and hook the <span style="color:blue">M3 hammer nut</span> at the back If you have the black PSU

alt alternative text

- Insert M3x8 screws here and hook the M3 hammer nut at the back If you have the old version silver PSU. Replace the old bottom cap with the new one so that wires can go from the bottom.

alt alternative text

- Install the PSU on the frame, make sure the screws are tightened properly

### 4.6 LCD

- Take the LCD supports, the installation for LCD support is the same as original ones. You can refer to the guide here: [https://help.prusa3d.com/en/guide/6-lcd-assembly_172423](https://help.prusa3d.com/en/guide/6-lcd-assembly_172423)

- Connect the electronics first, make sure you have the correct wires.

- Use the <span style="color:blue">M5x10 button cap screws</span> and hammer nut to fix the LCD on the main frame. The wires should be able to bend and go through the bottom of the base.

alt alternative text

alt alternative text

### 4.7 Endcaps

- Install the endcaps with M4x5 set screws

alt alternative text

## 5. The Dual Belt Plus system

### 5.1 Remove the original Y axis parts

- Turn the printer sidewise, make sure the printer stay still

- Take off the original Y belt holder and the orignal Y belt from the Y carriage

### 5.2 Install the new Y-Belt-Holder-A

- Take the Y-Belt-Holder-A and install it to the Y carriage using two M3x10 screws as shown. Make sure you have the correct orientation.

alt alternative text

### 5.3 Assemble the Y tensioner

If you have the older Dual Belt instead of Dual Belt Plus, please refer to the archive [here](./DB.md)

- The printed parts should look the same as shown in the picture. Note that this part is not symmetric.

alt alternative text | alt alternative text

- Insert your hex key into the Y tensioner and place the bearings on the hex key one by one as shown. Guide the bearings and insert the hex key all the way through the Y tensioner. Note that you shall insert from the side which is not chamfered.

- alt alternative text

- The bearings should look as shown.

- alt alternative text

- Now, insert the pin from the **chamfered side** and use the pin to replace and push the hex key out of the bearings. 

- alt alternative text

Insert the pin all the way to the end. Use a 3mm hex key to assist and make sure the pin is at the end.

- alt alternative text

The new Dual Belt Plus tensioner is complete!

- alt alternative text

- Pass the two belts through the Y tensioner as shown.

alt alternative text

- Connect the timing belt as shown. Make sure the belts reach the end. Otherwise, the belt length will be different.

alt alternative text

Insert the M3x32mm screw(the longest one) into the Y tensioner. 

alt alternative text

- Install the timing belt into the Y-Belt-Clip as shown. Put 2 M3x12 screws in advance.

alt alternative text

- Put Y Belt Clip into Y Belt Holder B, the upper cover of the Y holder.

- Attach Y Belt Holder B to Y Belt Holder A. Make sure you turn the screws on both sides evenly in turn.

alt alternative text

### 5.4 The final assembly

- Put the Dual belt driving pulley on the Y motor shaft, as close to the motor side as possible, leaving a very small gap only. Make sure the pulley is not touching the motor.

alt alternative text

- Put the timing belt around the pulley, let the teeth match the belt

alt alternative text

- Install the adjusting screw(M3x12mm) and leave a proper distance. If the belt does not fully match the driving pulley or the left and right belt does not have the same tension. Just move the Y carriage back and forth when the belt is under tension until the two belts are working properly.

- We will fine tune the belt tension later according to the printing test.

alt alternative text

- The Y tensioner  should be installed as shown.

alt alternative text

## 6. Replace the E motor (additional)

Prorifi3D E motors have the same dimension as the original one. It is a direct replacement. You can refer to this section to rebuild the E axis:[https://help.prusa3d.com/en/guide/5-e-axis-assembly_28536](https://help.prusa3d.com/en/guide/5-e-axis-assembly_28536)

## 7. Electronics

- The electronics are the same as the original i3. You can find the reference here:[https://help.prusa3d.com/en/guide/8-electronics-assembly_34416](https://help.prusa3d.com/en/guide/8-electronics-assembly_34416)

- Do this before install the control box

## 8. Install the control box

- Hook the control box on the holder as shown.

alt alternative text

- Tighten the screws.

alt alternative text

## 9. Spool holder

- Install the spool holder with flat cap M5x10 screws and hammer nuts.

## 10. Performance boost 

### 10.1 Install the heat sinks

- To get an extra performance boost, you can install the heatsink first. This will lower the motor running temperature, allowing a larger current and better stability.

- For Y motors we recommend you install as shown:

alt alternative text

- For X motors we recommend you install as shown:

alt alternative text

### 10.2 Changing the motor current

- You can change the current via Gcode

- First, connect your printer using USB cable

- Use Pronterface to connect your printer

- Change the RMS current of your XY motor using

```
M907 X520 Y520
```

- Change the steps per unit distance using

```
M92 Y80
```

- Save the settings by typing

```
M500
```

## 11. Belt tension adjust

- First set your belt to the lowest tension. You can use phone apps to determine the vibration frequency of your belt. The minimum value should be about 54Hz.

- You can use phone apps to measure the belt vibration frequency.

- When measuring the belt frequency, push the heated bed all the way to the back (where the motor is). Slightly picking the lower belt in the middle as shown. You can use a hex key to assist. For the Dual Belt system you only need to pick one of the belts.

alt alternative text

- Slowly tighten the belt, we recommend you tighten the belt to around **80Hz**. Which should give an overall good result. 

- Print the test block and you shall see no 2mm patterns and MRR should be almost gone.

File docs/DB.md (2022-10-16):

# The Dual Belt System

## Install the Dual Belt on Original i3

### 1.1 Remove the original Y axis parts

- Turn the printer sidewise, make sure the printer stay still

- Take off the original Y belt holder and the orignal Y belt from the Y carriage

### 1.2 Install the new Y-Belt-Holder-A

alt alternative text

- Take the Y-Belt-Holder-A and install it to the Y carriage using two M3x10 screws as shown. Make sure you have the correct orientation.

### 1.3 Assemble the Y tensioner

alt alternative text

- Push the nylon nut into the Y tensioner base as shown, there are four of them. Make sure you have the correct orientation!

alt alternative text

- Insert the pin into the Y tensioner block about 2/3 as shown and be careful with the plastic, do not break it.  

alt alternative text

alt alternative text

- Put the bearings on the pin as shown. Make sure the bearings have the correct orientation and order.

alt alternative text

- Insert the whole pin into the Y tensioner.

alt alternative text

- Pass the two belts through the Y tensioner as shown.

alt alternative text

- connect the timing belt as shown. Make sure the belts reach the end. Otherwise, the belt length will be different.

alt alternative text

- Insert the M3*32mm screw(the longest one) into the Y tensioner. 

alt alternative text

- Install the timing belt into the Y-Belt-Clip as shown. Put 2 M3x12 screws in advance.

alt alternative text

- Put Y Belt Clip into Y Belt Holder B, the upper cover of the Y holder.

- Attach Y Belt Holder B to Y Belt Holder A. Make sure you turn the screws on both sides evenly in turn.

### 1.4 The final assembly

- Put the Dual belt driving pulley on the Y motor shaft, as close to the motor side as possible, leaving a very small gap only. Make sure the pulley is not touching the motor.

alt alternative text

- Put the timing belt around the pulley, let the teeth match the belt

alt alternative text

- Install Y tensioner mount to the original position using the original screws. 

alt alternative text

- Install the adjusting screw(M3x12mm) and leave a proper distance. If the belt does not fully match the driving pulley or the left and right belt does not have the same tension. Just move the Y carriage back and forth when the belt is under tension until the two belts are working properly.

- We will fine tune the belt tension later according to the printing test.

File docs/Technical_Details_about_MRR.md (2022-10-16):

<iframe width="560" height="315" src="https://www.youtube.com/embed/-et5eMyLlUs" title="YouTube video player" frameborder="0" allow="accelerometer; autoplay; clipboard-write; encrypted-media; gyroscope; picture-in-picture" allowfullscreen></iframe>

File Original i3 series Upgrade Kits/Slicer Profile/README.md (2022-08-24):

# How to use our Profile
## STEP1:[Download](https://github.com/Prorifi3D-Official/Prorifi3D-Upgrades/tree/main/Original%20i3%20series%20Upgrade%20Kits/Slicer%20Profile/PrusaSlicer_config_Prorifi3D_bundle.ini) our profile

## STEP2:Import the configs

- ### You can find the import at File->import->import config bundle

- ### Then import the profile you just downloaded

## STEP3:Check the profile
- ### you should see 5 settings were imported

- ### check the presets and you can find new profiles there!

## STEP4:Print
- ### Happy printing!
:wink:

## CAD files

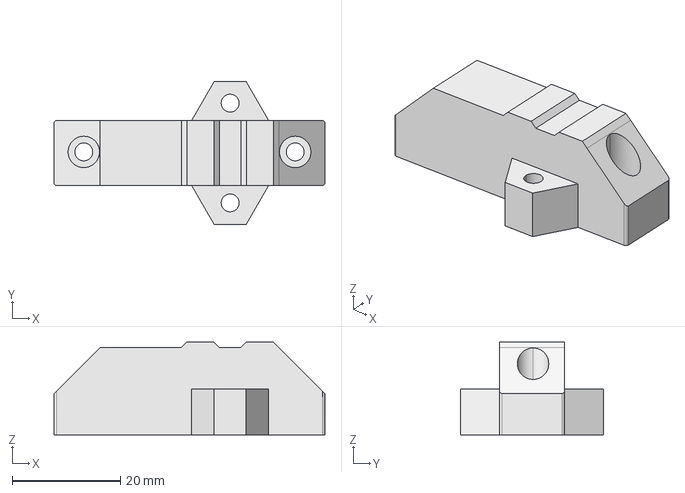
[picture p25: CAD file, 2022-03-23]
Original i3 series Upgrade Kits/Stage 1 Upgrade/Dual Belt/STEP/Y-Belt-Holder-A.step
50.0 x 26.4 x 17.1 mm

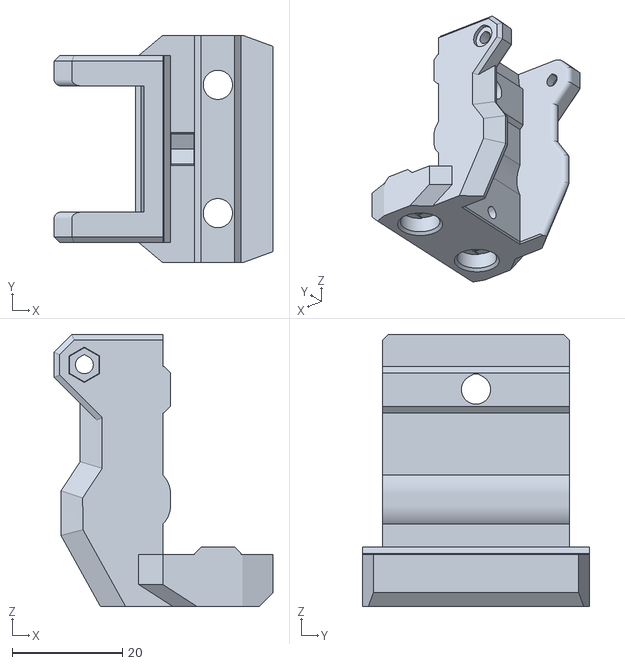
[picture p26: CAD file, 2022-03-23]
Original i3 series Upgrade Kits/Stage 1 Upgrade/For Bear i3/Beta Tester Only/STL/Bear-y-idler-mount.stl
39.8 x 41.3 x 49.4

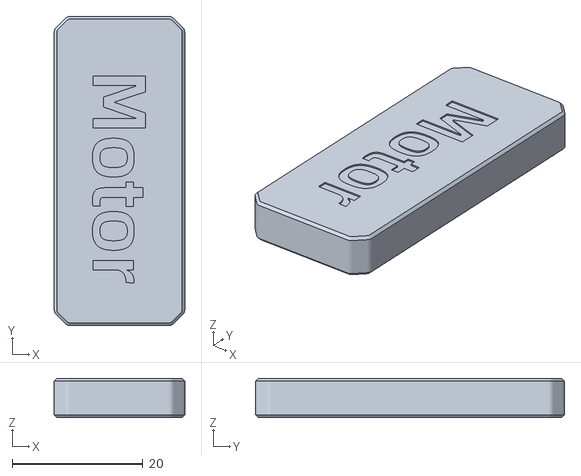
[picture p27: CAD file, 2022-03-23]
Original i3 series Upgrade Kits/Stage 1 Upgrade/For Bear i3/Jigs/Jig-Motor.stl
20.0 x 47.3 x 6.00

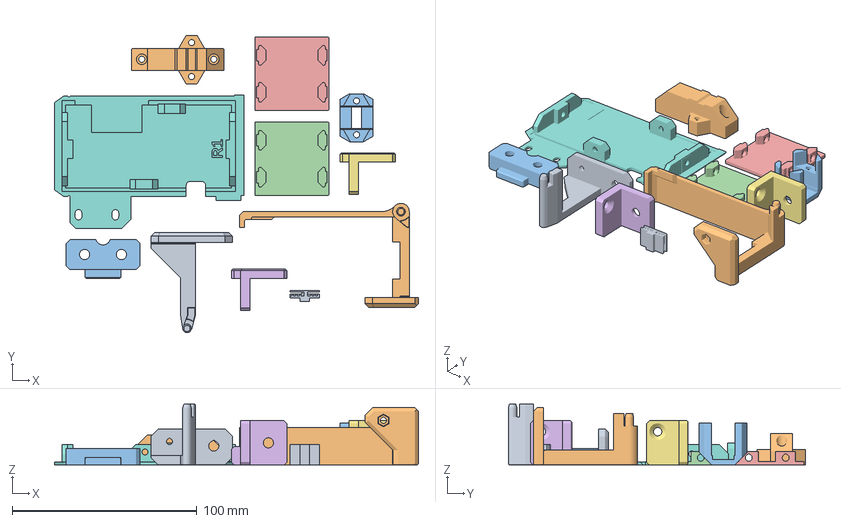
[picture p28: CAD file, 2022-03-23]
Original i3 series Upgrade Kits/Stage 2 Upgrade/Frame/STL/BLACK/3mf/All_Black_Printed_Parts.3mf
197.2 x 161.1 x 33.0 mm
Y-Belt-Clip.stl
Y-Belt-Holder-A.stl
Y-Belt-Holder-B.stl
(2)-Bottomcover.stl
(2)-PSU-Holder.stl
(Silver PSU only)-PSU-Cover-Lid.stl
Electronics-Cover-Holder-A.stl
Electronics-Cover-Holder-B.stl
Electronics-Cover-Holder-C.stl

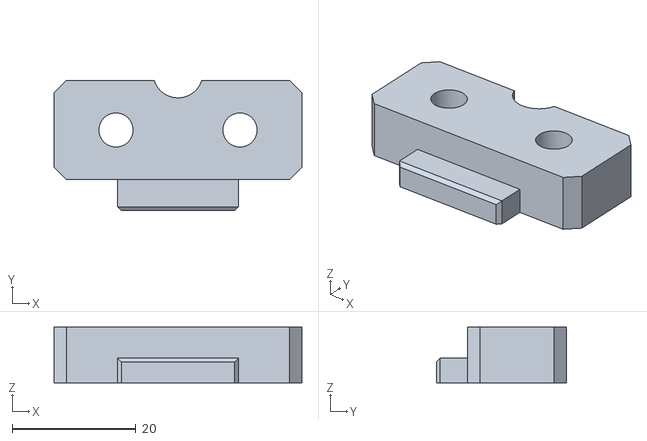
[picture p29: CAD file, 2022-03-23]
Original i3 series Upgrade Kits/Stage 2 Upgrade/Frame/STL/BLACK/Electronics-Cover-Holder-C.stl
40.0 x 21.0 x 9.00

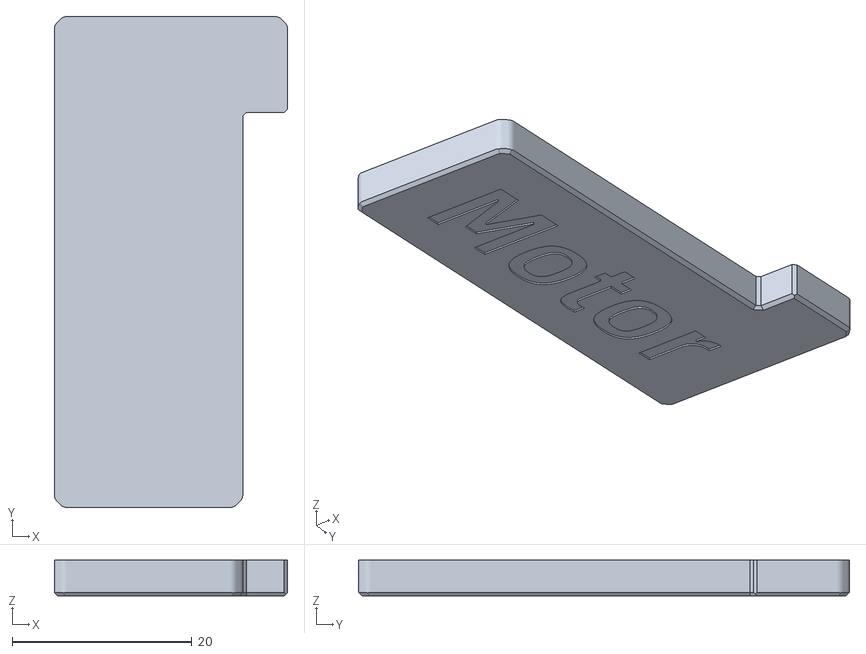
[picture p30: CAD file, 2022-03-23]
Original i3 series Upgrade Kits/Stage 2 Upgrade/Frame/STL/Jigs/Jig-Motor.stl
26.0 x 54.7 x 4.00

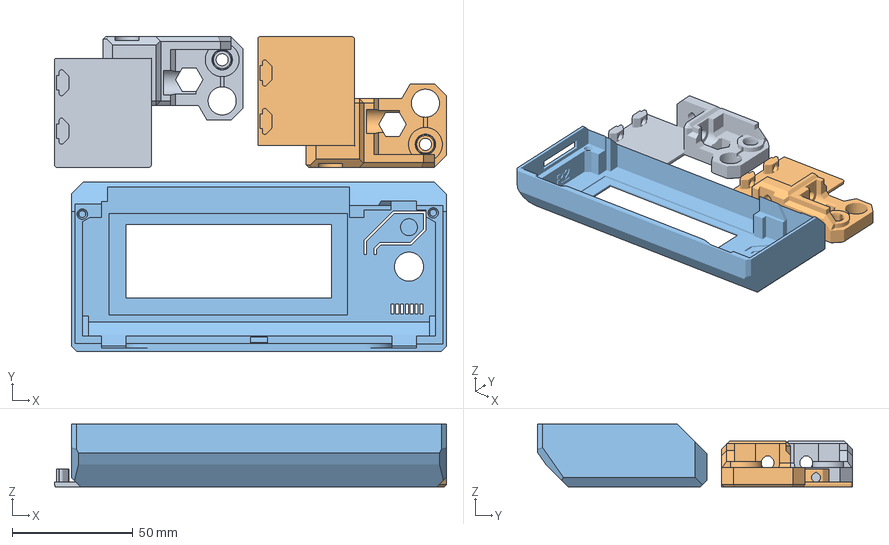
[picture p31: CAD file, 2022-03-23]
Original i3 series Upgrade Kits/Stage 2 Upgrade/Frame/STL/MIX COLOR/3mf/All_mix_color_parts.3mf
162.0 x 130.0 x 26.0 mm
Z-Top-L.stl
Z-Top-R.stl
LCD-Cover.stl

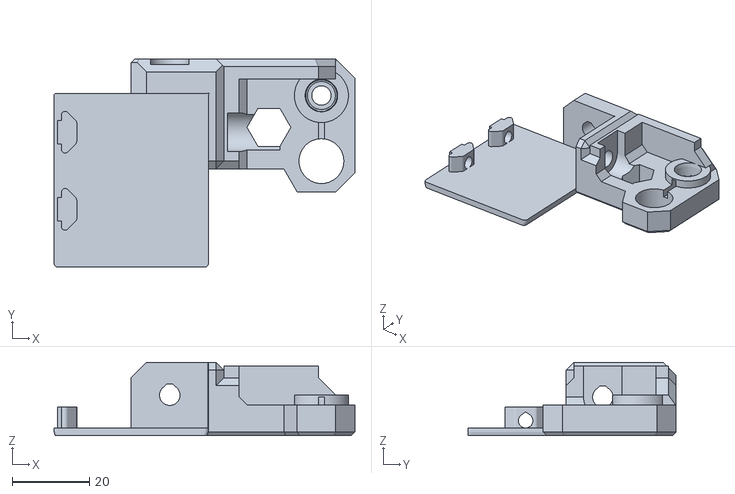
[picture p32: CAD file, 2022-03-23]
Original i3 series Upgrade Kits/Stage 2 Upgrade/Frame/STL/MIX COLOR/Z-Top-L.stl
78.0 x 54.0 x 19.0

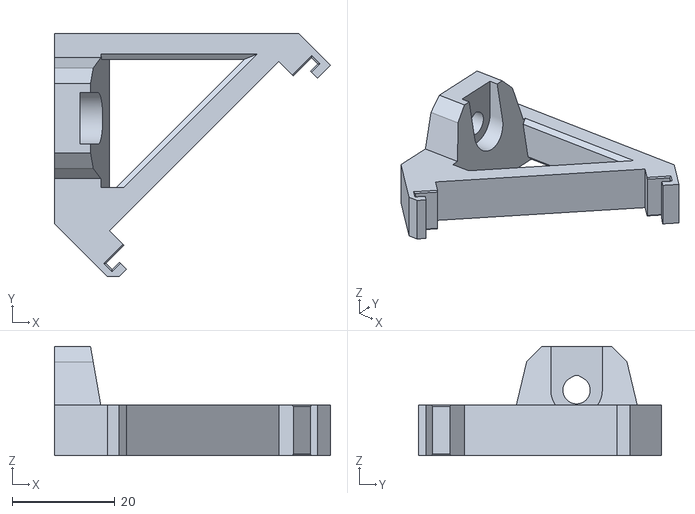
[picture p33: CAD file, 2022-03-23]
Original i3 series Upgrade Kits/Stage 2 Upgrade/Frame/STL/WATER BLUE/LCD-Support-B.stl
53.6 x 47.2 x 21.2

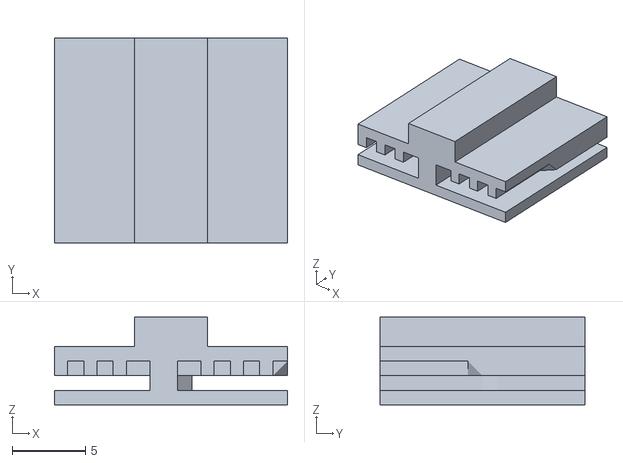
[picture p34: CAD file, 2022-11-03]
Original MINI series Upgrade Kits/MINI Upgrade/Dual Belt/STL/DB+Clip_6mm.STL
15.9 x 14.0 x 6.00

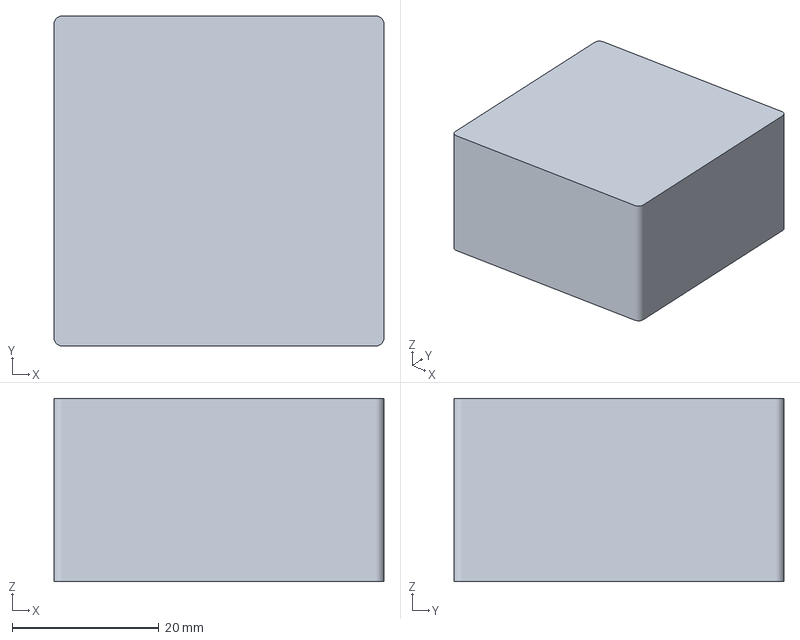
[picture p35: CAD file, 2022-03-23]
Test files/Speed_Tower_25_40.3mf
45.0 x 45.0 x 25.0 mm

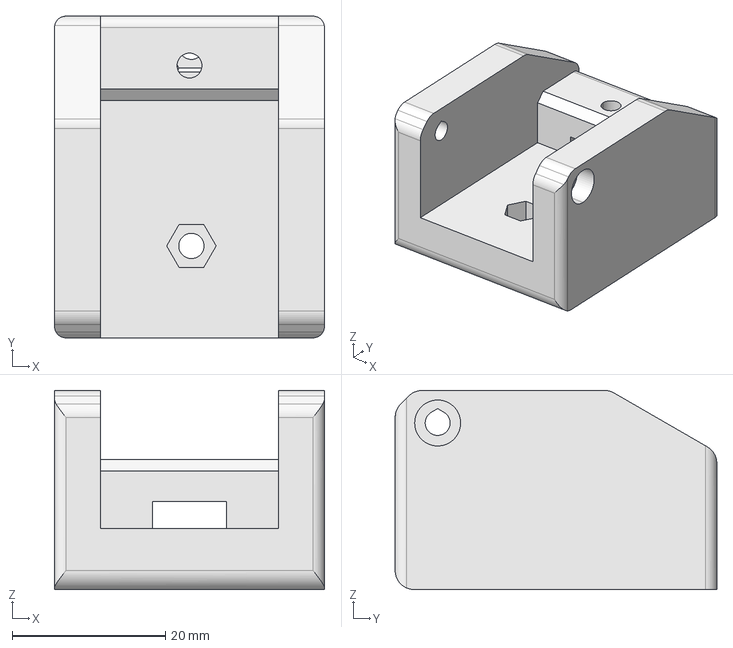
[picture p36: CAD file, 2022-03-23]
Original i3 series Upgrade Kits/Stage 1 Upgrade/Dual Belt/STEP/Y-Belt-Idler-A.STEP
35.2 x 42.0 x 26.0 mm

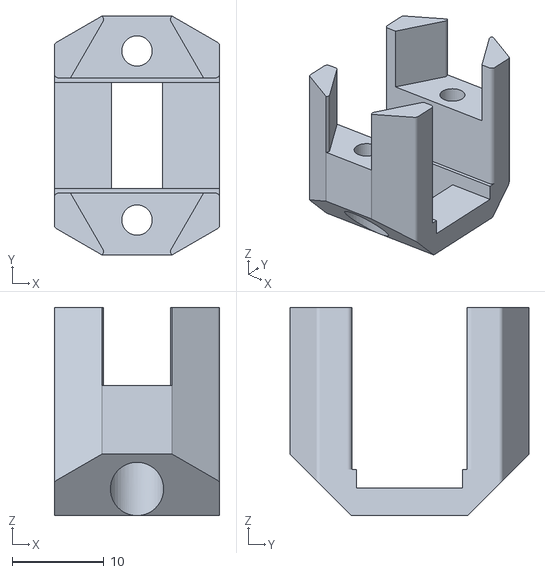
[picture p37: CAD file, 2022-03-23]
Original i3 series Upgrade Kits/Stage 1 Upgrade/For Bear i3/Beta Tester Only/STL/Y-Belt-Holder-B.stl
18.0 x 26.0 x 22.7

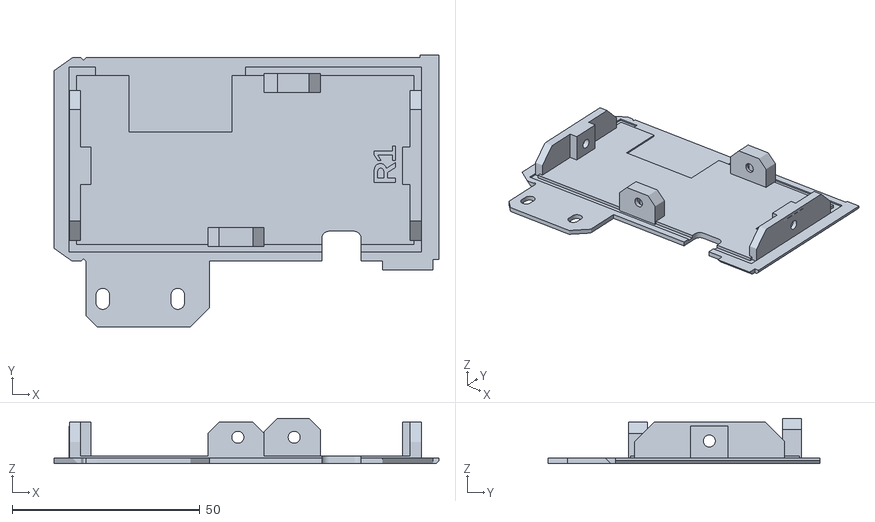
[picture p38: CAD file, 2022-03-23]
Original i3 series Upgrade Kits/Stage 2 Upgrade/Frame/STL/BLACK/(Silver PSU only)-PSU-Cover-Lid.stl
102.6 x 72.5 x 12.0

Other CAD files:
Original i3 series Upgrade Kits/Stage 1 Upgrade/For Bear i3/Jigs/Jig-Idler.stl
Original i3 series Upgrade Kits/Stage 2 Upgrade/Frame/STL/BLACK/3mf/Spool_holder.3mf
Original MINI series Upgrade Kits/MINI Upgrade/Dual Belt/STL/MINI+-Y-idler.STL
Original MINI series Upgrade Kits/MINI Upgrade/Dual Belt/STL/MINI_Y_belt_holder_A.STL
Original MINI series Upgrade Kits/MINI Upgrade/Dual Belt/STL/MINI_Y_belt_holder_B.STL
Original i3 series Upgrade Kits/Stage 1 Upgrade/Dual Belt/STEP/Y-Belt-Clip.STEP
Original i3 series Upgrade Kits/Stage 1 Upgrade/Dual Belt/STEP/Y-Belt-Holder-B.step
Original i3 series Upgrade Kits/Stage 1 Upgrade/Dual Belt/STEP/Y-Belt-Idler-B.step
Original i3 series Upgrade Kits/Stage 1 Upgrade/Dual Belt/STL/Y-Belt-Idler-A.stl
Original i3 series Upgrade Kits/Stage 1 Upgrade/Dual Belt/STL/Y-Belt-Idler-B.stl
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

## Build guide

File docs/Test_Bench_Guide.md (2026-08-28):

---
hide:
  - navigation
---

# Printer Test Bench Guide

**Version:** R0.3

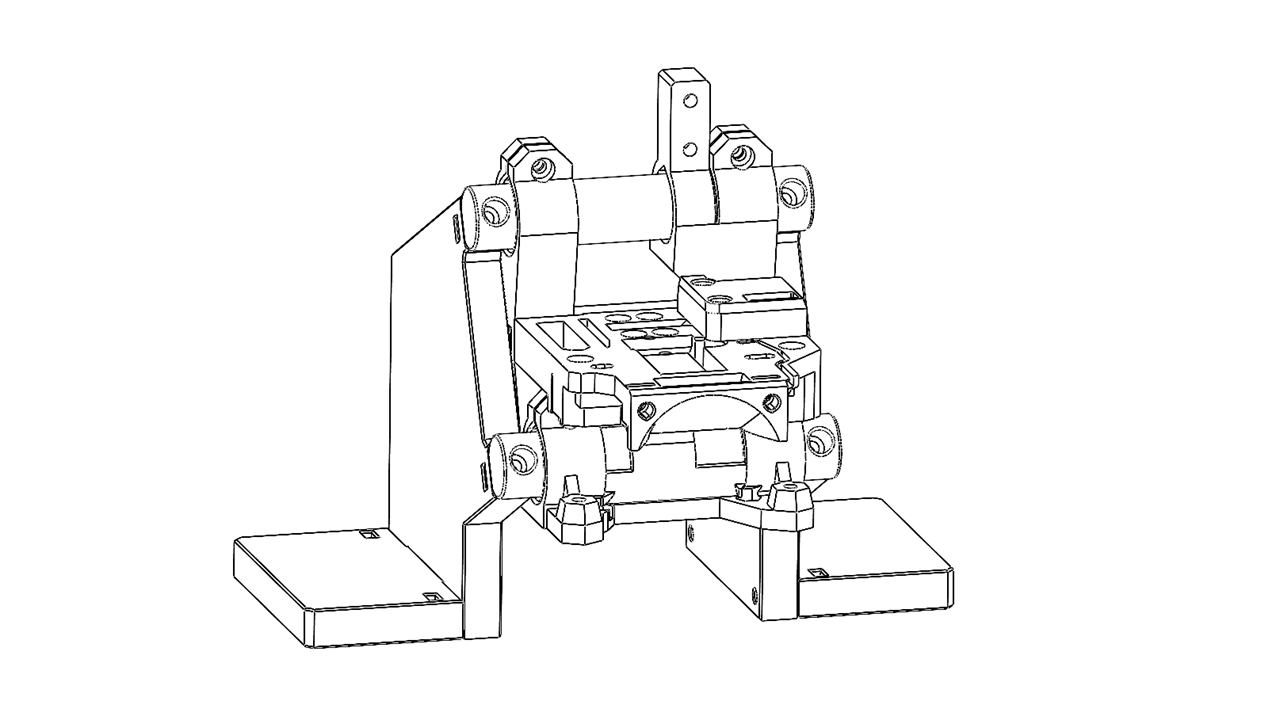
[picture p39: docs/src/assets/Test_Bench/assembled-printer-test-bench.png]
Assembled Printer Test Bench


> **Document purpose:** This guide covers the assembly, bring-up, calibration, and use of the Printer Test Bench. The bench uses a **P350 Basic Tool Head** as the standard test module.

---

## 0. Before You Start

### 0.1 Package Scope: Included and Customer-Supplied Components

The Printer Test Bench Kit provides the fixture, P350 Tool Head, sensor, and ESP interface hardware. A complete extrusion and printer-control system is not included.

<div class="test-bench-package-scope" role="group" aria-label="Package contents and customer-supplied components">
  <section class="scope-card scope-card--included">
    <header class="scope-card__header">
      <span class="scope-card__eyebrow">KIT CONTENTS</span>
      <h4>Included with the Kit</h4>
    </header>
    <ul class="scope-card__list">
      <li><strong>Test-bench frame</strong><span>Base plates, vertical supports, and Tool Head support beams</span></li>
      <li><strong>Assembly hardware</strong><span>M3 thin square nuts and the required M3 screws</span></li>
      <li><strong>P350 module</strong><span>P350 Basic Tool Head with the integrated sensor section</span></li>
      <li><strong>Interface hardware</strong><span>ESP board/interface and Tool Head signal cable</span></li>
    </ul>
  </section>
  <section class="scope-card scope-card--required">
    <header class="scope-card__header">
      <span class="scope-card__eyebrow">USER-SUPPLIED</span>
      <h4>User Must Provide</h4>
    </header>
    <ul class="scope-card__list">
      <li><strong>Extrusion system</strong><span>A compatible extruder and extruder motor</span></li>
      <li><strong>Hot-end system</strong><span>A compatible hot end with a heater, thermistor, and hot-end cooling fan</span></li>
      <li><strong>Printer control</strong><span>A Marlin-compatible controller board/mainboard and the appropriate firmware</span></li>
      <li><strong>Host connection</strong><span>A Windows 10 or 11 64-bit PC, compatible USB data cables, and required board drivers</span></li>
    </ul>
  </section>
</div>

> ⚠️ **Before bring-up:** Obtain and install every item in the customer-supplied column before starting calibration or functional testing.

#### Who is this for?

*   Makers who want to research, develop, or evaluate systems using P350 Basic Tool Heads.
    
*   Technicians performing repeated functional, endurance, or sensor tests.
    
*   Users who want to build or experiment with a custom 3D-printer test setup.

#### Who might reconsider?

*   First-time 3D-printing users with no experience assembling, wiring, or configuring printer hardware.

---

### 0.2 Intended Use and Test Scope

#### The bench is intended to test

*   Flow condition
    
*   Hot-end flow response
    
*   Extrusion force

#### Environmental limits

| Item | Requirement |
| --- | --- |
| Ambient temperature | Room temperature |
| Work surface | Flat, stable, and non-combustible |
| Ventilation | Adequate ventilation when testing ABS or similar materials |

---

### 0.3 Estimated Time and Difficulty

| Stage | Estimated time | Key challenge | Experience needed |
| --- | --- | --- | --- |
| 1. Test Bench Frame | 10 min | Alignment and rigidity | Basic hands-on experience |
| 2. Basic Tool Head | 5 min | Correct interface and cable clearance | P350 familiarity helpful |
| 3. Wiring and Control Hardware | 10 min | Pinout verification | Electrical-safety awareness |
| 4. Calibration | 15 min | Repeatable datum and measurement | Careful measurement |
| **Total** | **40 min** |  |  |

We recommend validating each module before moving to the next stage.

---

### 0.4 Guide Symbols

| Symbol | Element | Purpose |
| --- | --- | --- |
| 🔵 | **Completion Criteria** | The exact condition that confirms the step is complete. |
| 🟡 | **Common Mistake** | A frequent error and how to avoid it. |
| 🔴 | **Rollback** | The minimum disassembly or adjustment needed to correct an error. |
| ✔️ | **Note** | Helpful information or a reminder. |
| ⚠️ | **Caution** | Risk of part damage, unreliable results, or significant rework. |
| ☠️ | **Danger** | Risk of injury, fire, electrical shock, or catastrophic damage. |
| `- [ ]` | **Check Box** | Used to record progress and inspection status. |

---

## 1. Modular Assembly Overview

The Printer Test Bench is divided into independently verifiable modules. A problem in one module should not require a complete rebuild of the entire test bench.

| Module | Contents | Completion criteria |
| --- | --- | --- |
| 1. Test Bench Frame | Base, vertical support, structural parts, and covers | Bench is rigid and stable on a flat surface |
| 2. P350 Tool Head | P350 Basic Tool Head, sensor components, and bench mounting hardware | Tool Head is retained, aligned, and removable |
| 3. Extrusion Hardware | Customer-supplied extruder, motor, hot end, and cooling hardware | Components are securely installed and mechanically aligned |
| 4. Wiring and Control Hardware | Supplied ESP board/interface hardware and customer-supplied controller board | Connections are verified and strain-relieved |
| 5. Firmware / Test Interface | Configuration, controls, and communication interfaces | Software connects and devices respond correctly |
| 6. Calibration | Extrusion and sensor reference procedures | Required calibration steps are completed |

---

## Part I - Mechanical Assembly

### 2. Test Bench Frame

#### 2.1 Before Assembly

##### Printed parts

*   Base plate — 2pcs
    
*   Side plate — 2 pcs
    
*   Support Beam — 2 pcs

##### Fasteners

*   M3 square nut (thin) — 8 pcs
    
*   M3 x 18 — 4 pcs
    
*   M3 x 14 — 4 pcs

##### Tools

*   2.0 mm and 2.5 mm hex keys
    
*   Flat, stable work surface

##### Workspace

*   Flat work surface at least 200 mm x 200 mm
    
*   Minimum clearance around the bench: 100 mm

---

#### 2.2 Printed Part Preparation

**Estimated time:** 5 min

1.  **Inspect the base plate.** Confirm that all mounting holes, slots, and locating features are free of debris.
    
2.  **Identify the front and rear.** Position the base plate as shown. Orient the frame so that the indicated front side faces you.
    
    Identify and orient the test-bench frame parts
    
3.  **Insert the square nuts.** Insert the M3 thin square nuts into the indicated slots, as shown.

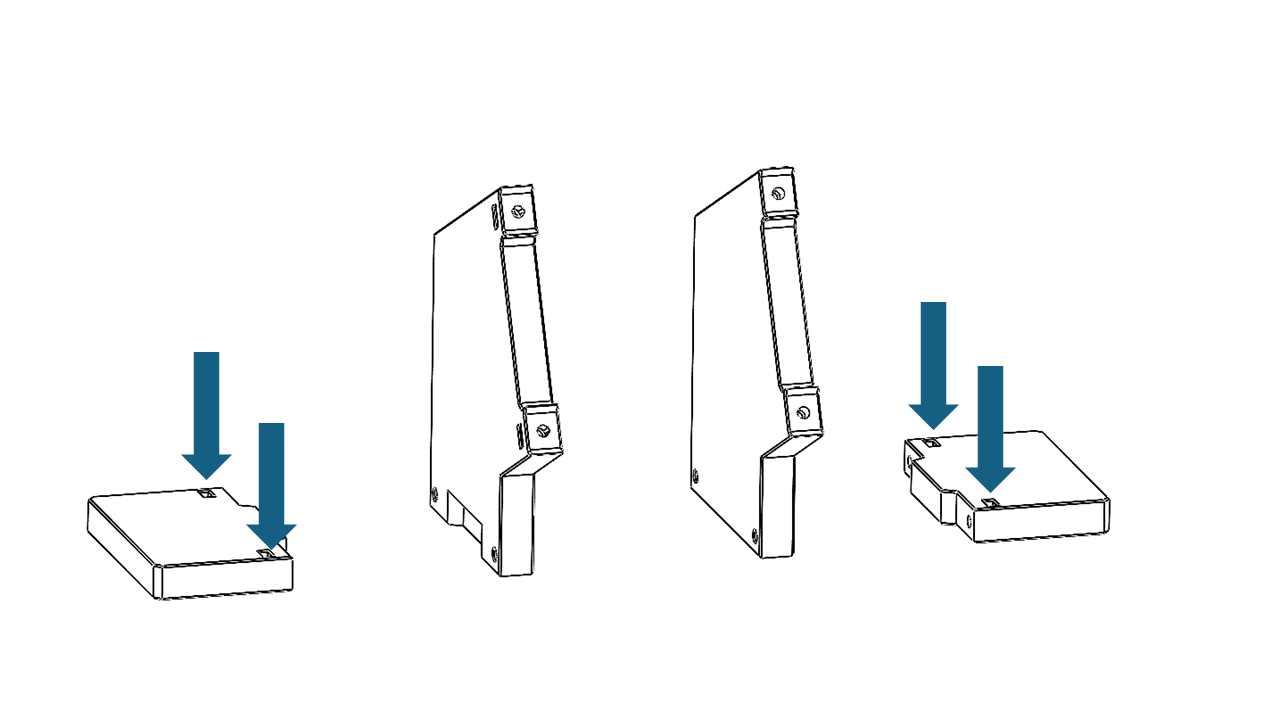
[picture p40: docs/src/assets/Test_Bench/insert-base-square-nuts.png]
Insert the square nuts into the base plates


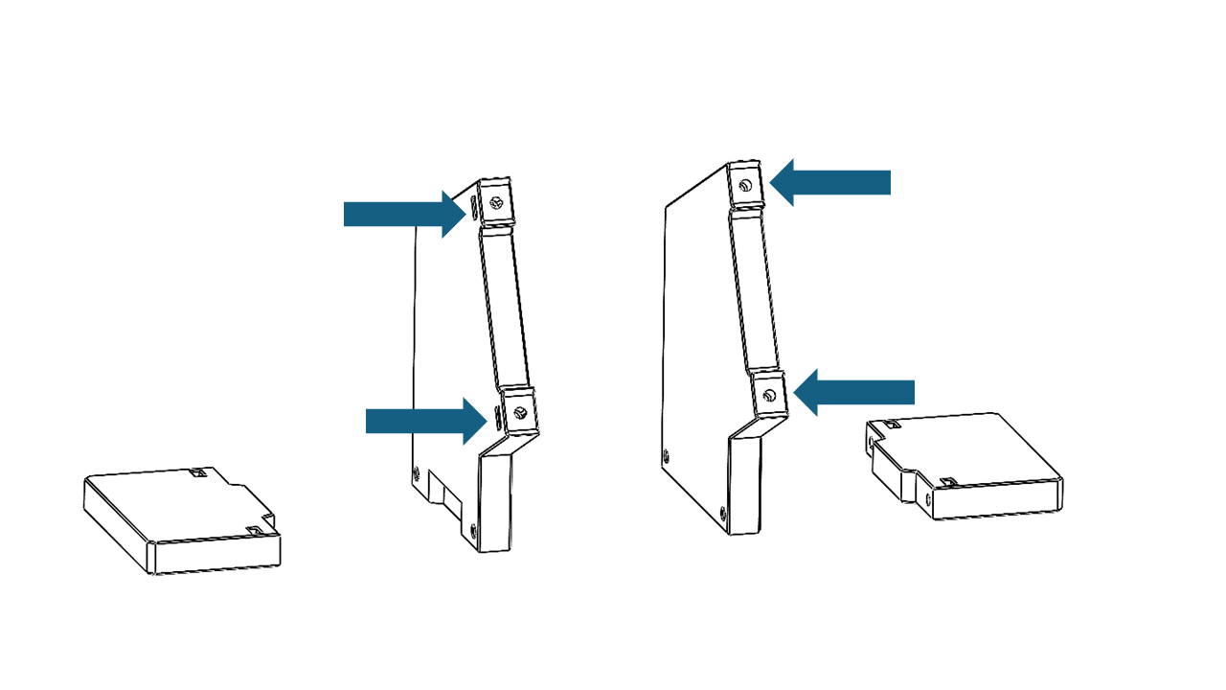
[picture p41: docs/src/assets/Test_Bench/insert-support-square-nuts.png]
Insert the square nuts into the vertical supports


> 🟡 **Common Mistake:** Forgetting to insert the square nuts before installing the next part.

> 🔵 **Completion Criteria:** All required square nuts are fully inserted and correctly positioned.

---

#### 2.3 Vertical Support Installation

**Estimated time:**  5 min

1.  **Position the vertical support.** Fit the vertical support onto the base plate as shown. Make sure the mating slots and locating features are aligned.
    
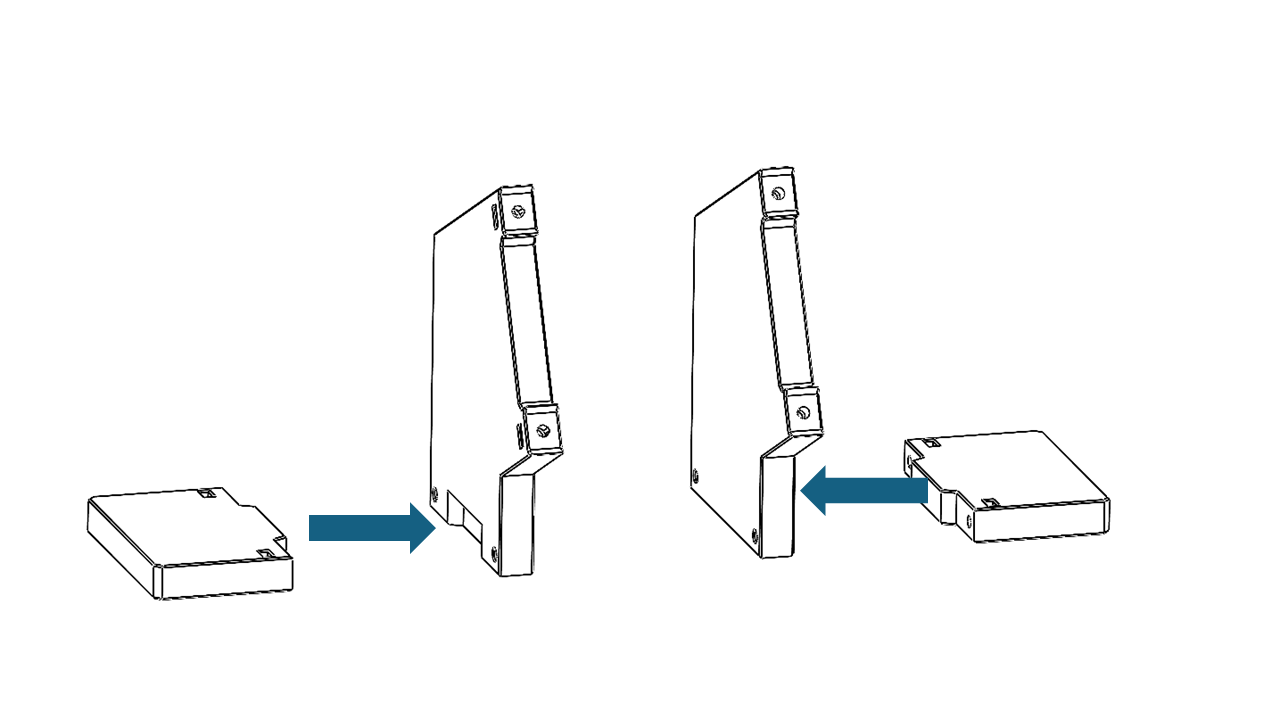
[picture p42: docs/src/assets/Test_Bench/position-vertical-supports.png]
Position the vertical supports on the base plates
    
    
2.  **Tighten in sequence.** Install the M3 × 18 mm screws and tighten them in the order shown, on both sides.

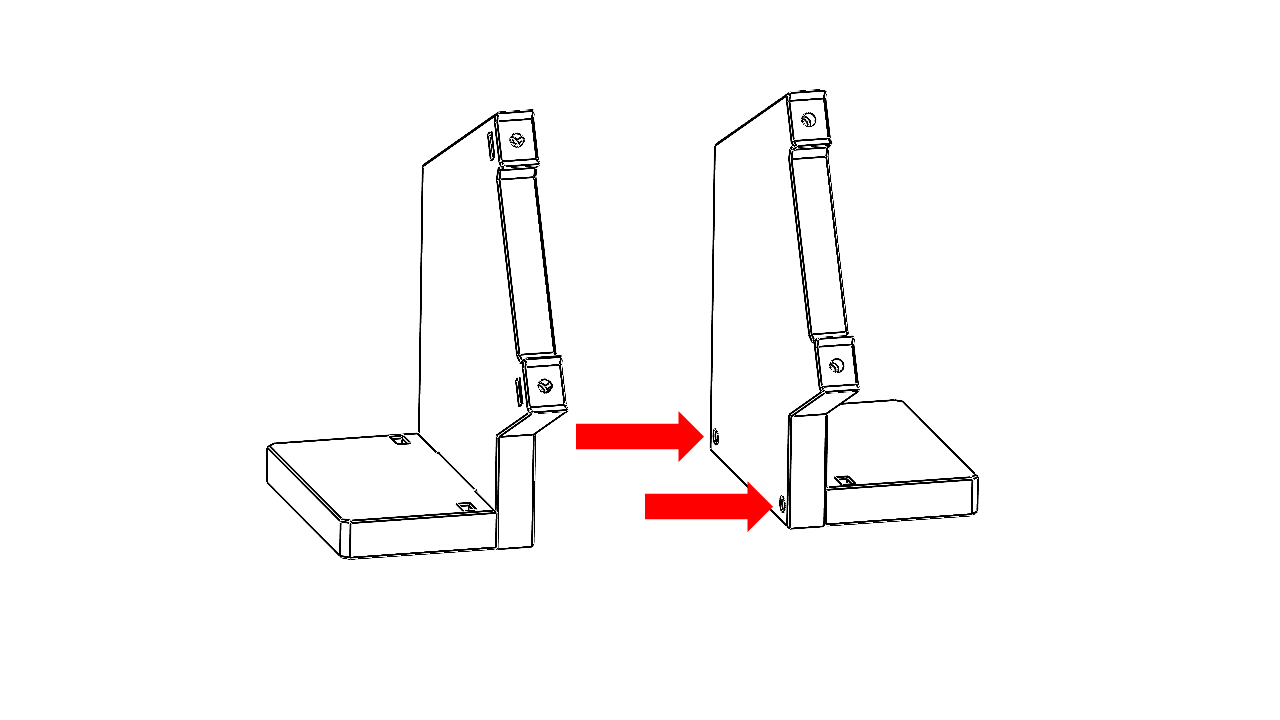
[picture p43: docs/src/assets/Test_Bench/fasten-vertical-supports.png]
Fasten both vertical supports


> 🔵 **Completion Criteria:** The vertical support is fully seated, does not visibly tilt, and does not move when moderate hand force is applied.

---

#### 2.4 Completion Check

Before continuing to Chapter 3, confirm the following:

*   [ ] The bench frame is rigid and sits flat without rocking.
    
*   [ ] All main structural parts are installed in the correct orientation.
    
*   [ ] All required access panels or covers can be removed as intended.
    
*   [ ] There are no sharp edges, trapped wires, or loose fasteners.
    
*   [ ] The Tool Head mounting points are ready for Chapter 3.

---

### 3. P350 Tool Head Installation

#### 3.1 Tool Head Preparation

1.  Prepare the P350 Basic Tool Head shown below.

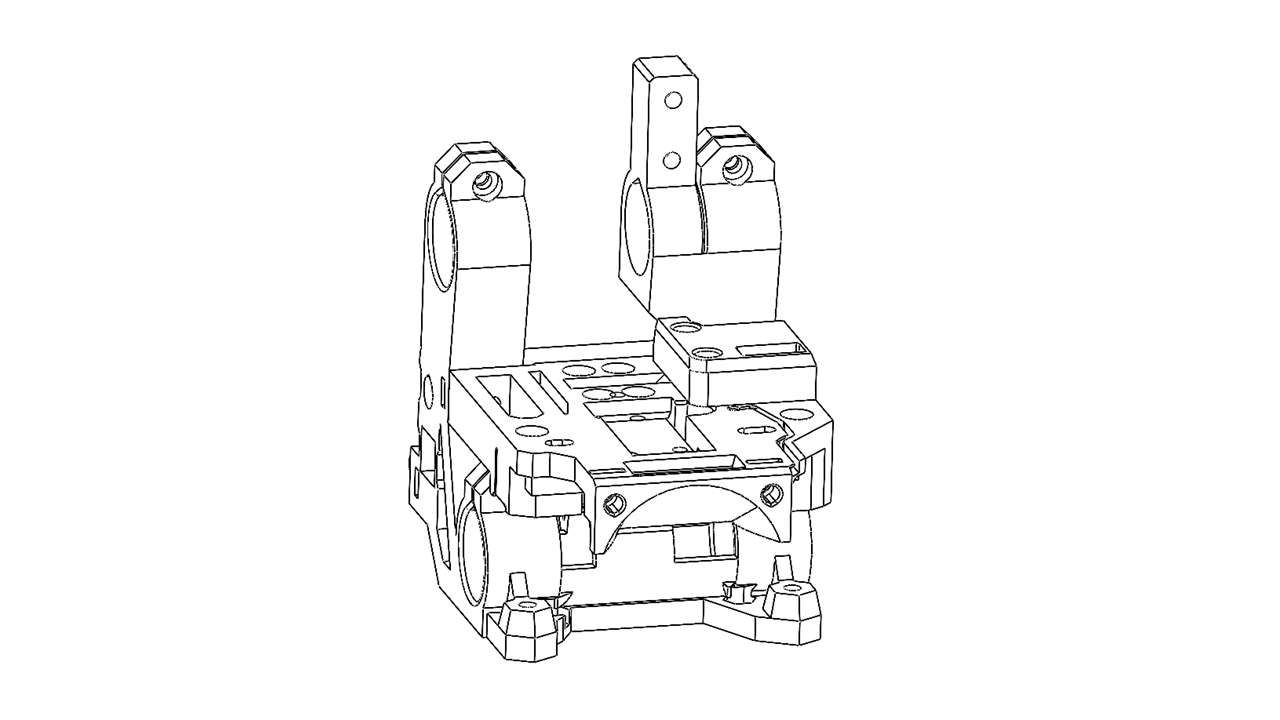
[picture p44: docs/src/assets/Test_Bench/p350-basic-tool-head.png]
P350 Basic Tool Head


---

#### 3.2 Required Preassembled Items

*   P350 Basic Tool Head Module — 1 pcs
    
*   Support beams — 2 pcs

---

#### 3.3 Mount the Basic Tool Head

1.  **Orient the Tool Head.** Insert the support beams as shown.
    
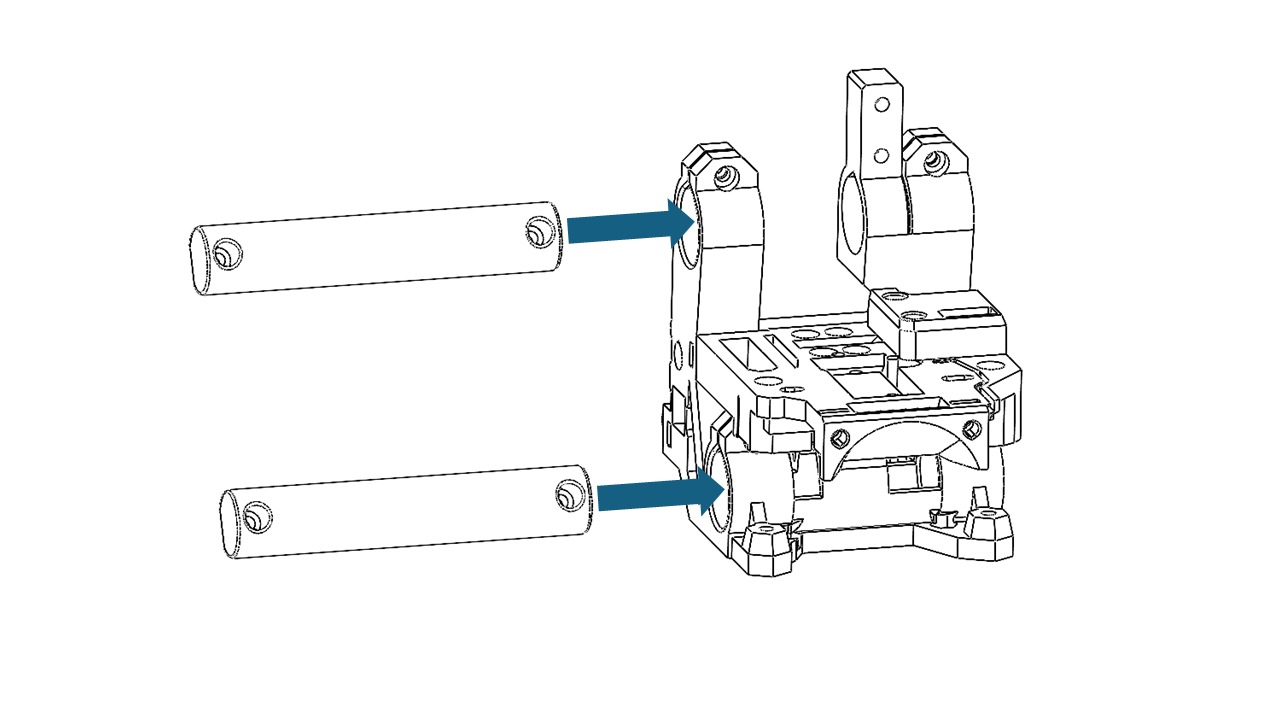
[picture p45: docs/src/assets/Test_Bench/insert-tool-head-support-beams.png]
Insert the support beams into the P350 Basic Tool Head
    
    
2.  **Secure the support beams.** Fasten the support beams using M3 × 14 mm screws.

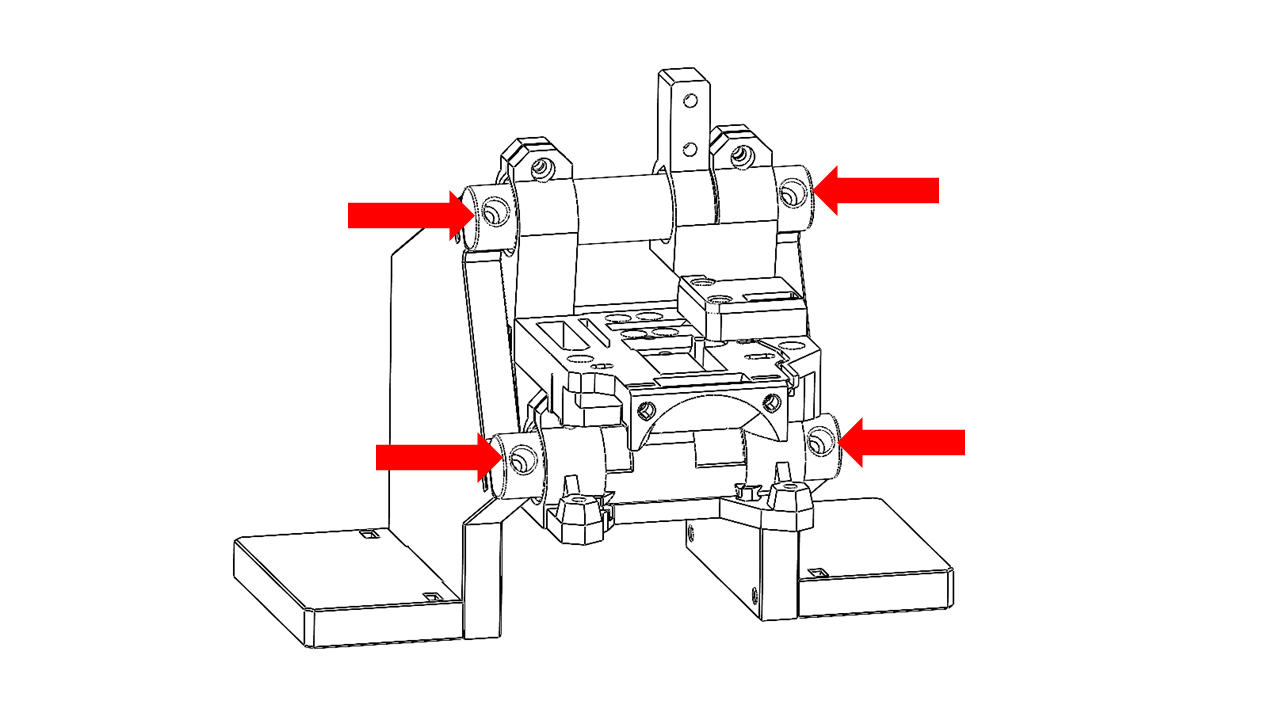
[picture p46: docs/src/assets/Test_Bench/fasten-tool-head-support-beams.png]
Fasten the Tool Head support beams


---

#### 3.4 Tool-Head Cable Pre-Routing

1.  Locate the signal cable and connect it to the designated pins on the Tool Head PCB.

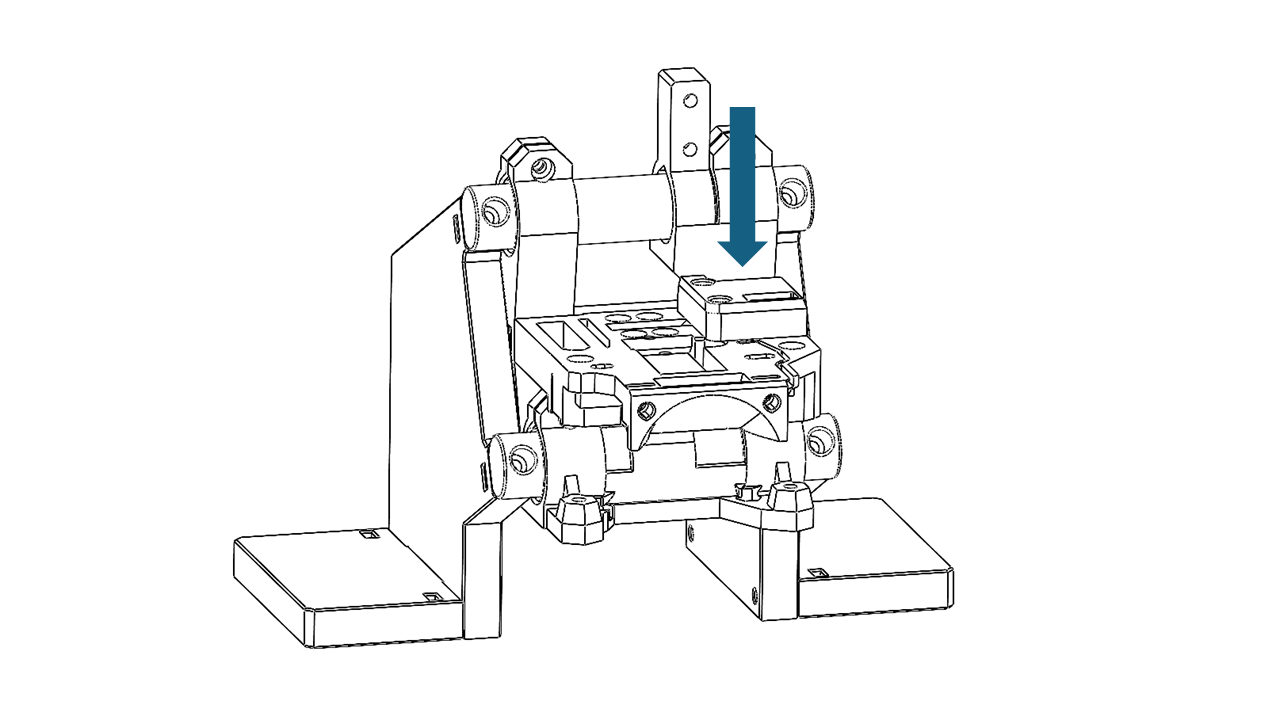
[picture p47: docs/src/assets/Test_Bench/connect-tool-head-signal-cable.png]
Connect the signal cable to the Tool Head PCB
    
    
2.  Locate the ESP board and connect the other end of the signal cable as shown.
    
3.  Connect the USB Type-C cable to the ESP board as shown. This connection will be used later for serial-port monitoring.

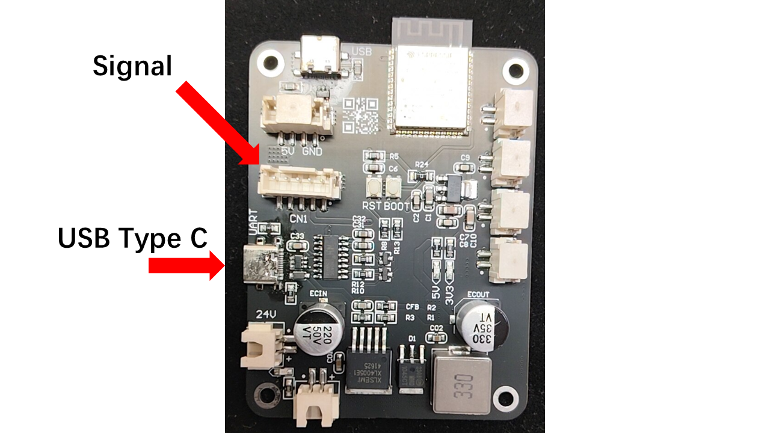
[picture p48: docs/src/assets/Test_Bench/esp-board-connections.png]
ESP board signal and USB Type-C connections
    

---

## Part II - Bring-Up and Testing

### 4. Hot End and Extruder Installation

> ⚠️ **Customer-Supplied Hardware:** The **extruder, extruder motor, hot end module, and 3D-printer controller board/mainboard are not included** with the test bench.

1.  The P350 Tool Head is compatible with mainstream extruders such as the Serpha Mini and Galileo 2.0. The extruder and its motor must be supplied by the buyer.
    
2.  Install the extruder in the orientation shown.
    
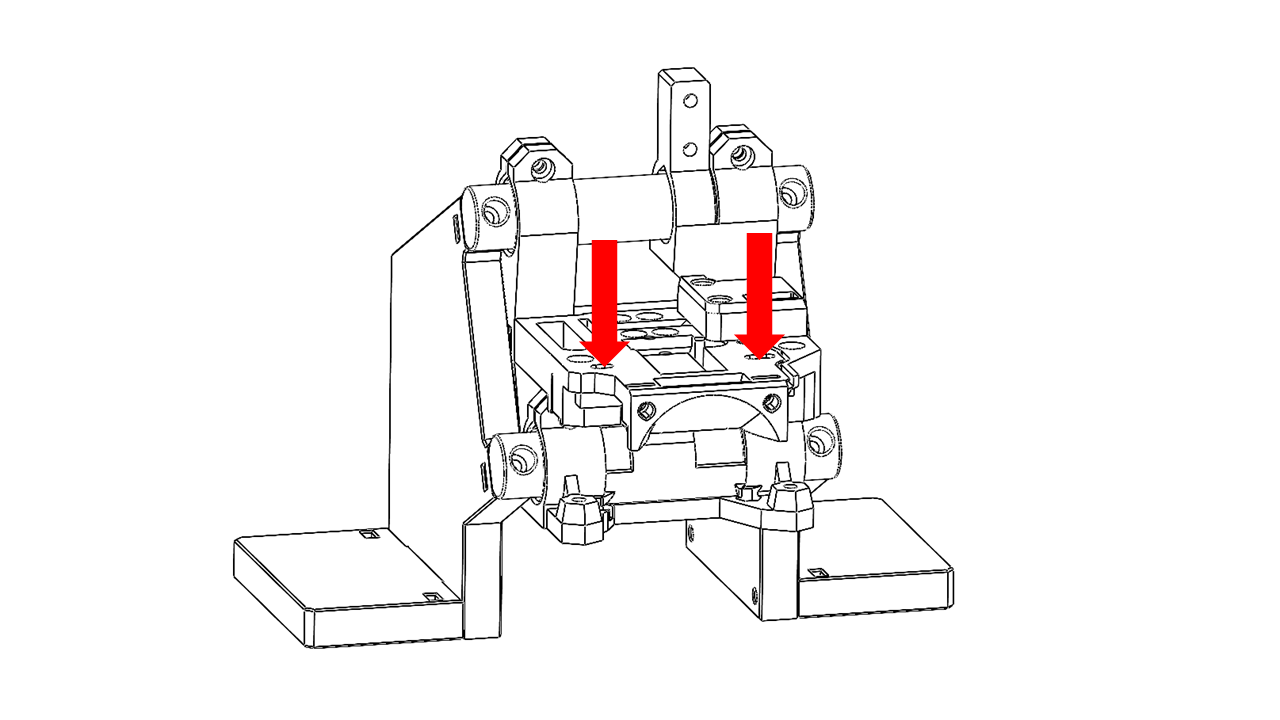
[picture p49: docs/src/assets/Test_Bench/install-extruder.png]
Install the extruder in the Tool Head
    
    
3.  The Tool Head is also compatible with mainstream hot ends such as the E3D V6. Hot-end configurations with mounting-hole center spacing of **13.16 mm or 16 mm** can be mounted on the Tool Head. Install the selected hot end as shown. Make sure your hotend is pre assembled with heating element and thermistor.
    
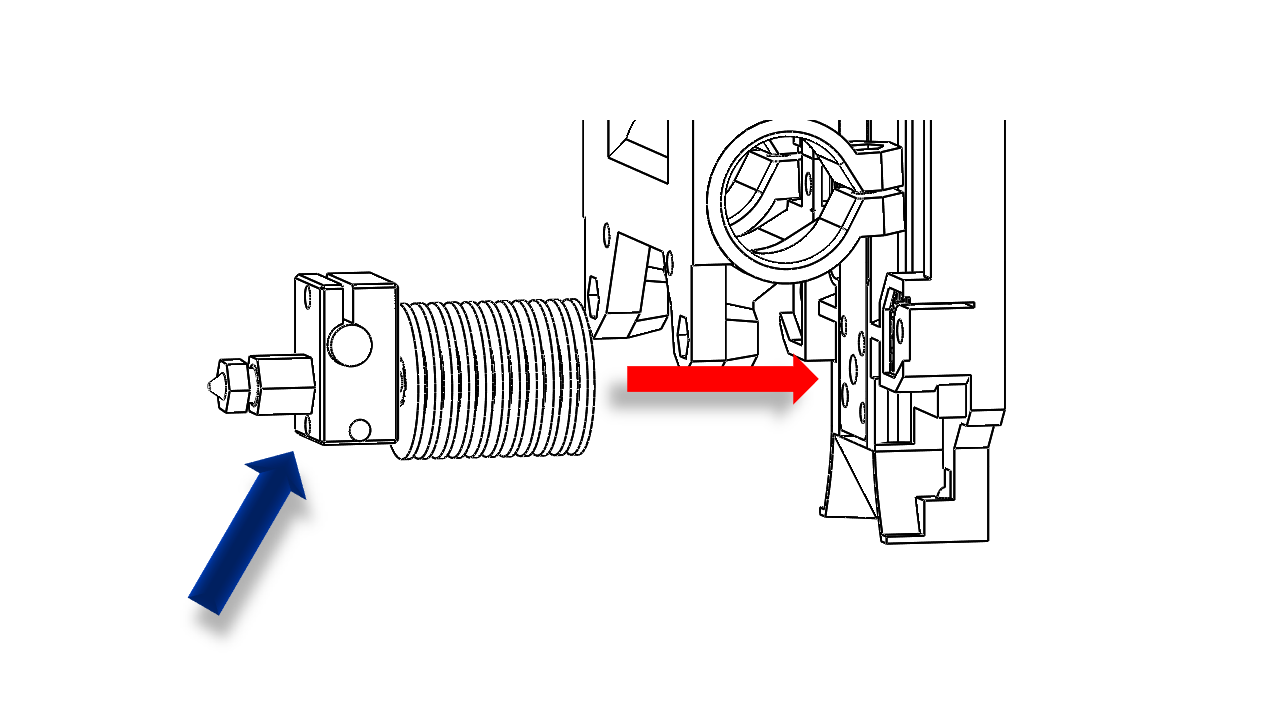
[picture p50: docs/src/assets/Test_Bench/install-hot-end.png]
Install the hot end in the Tool Head
    
    
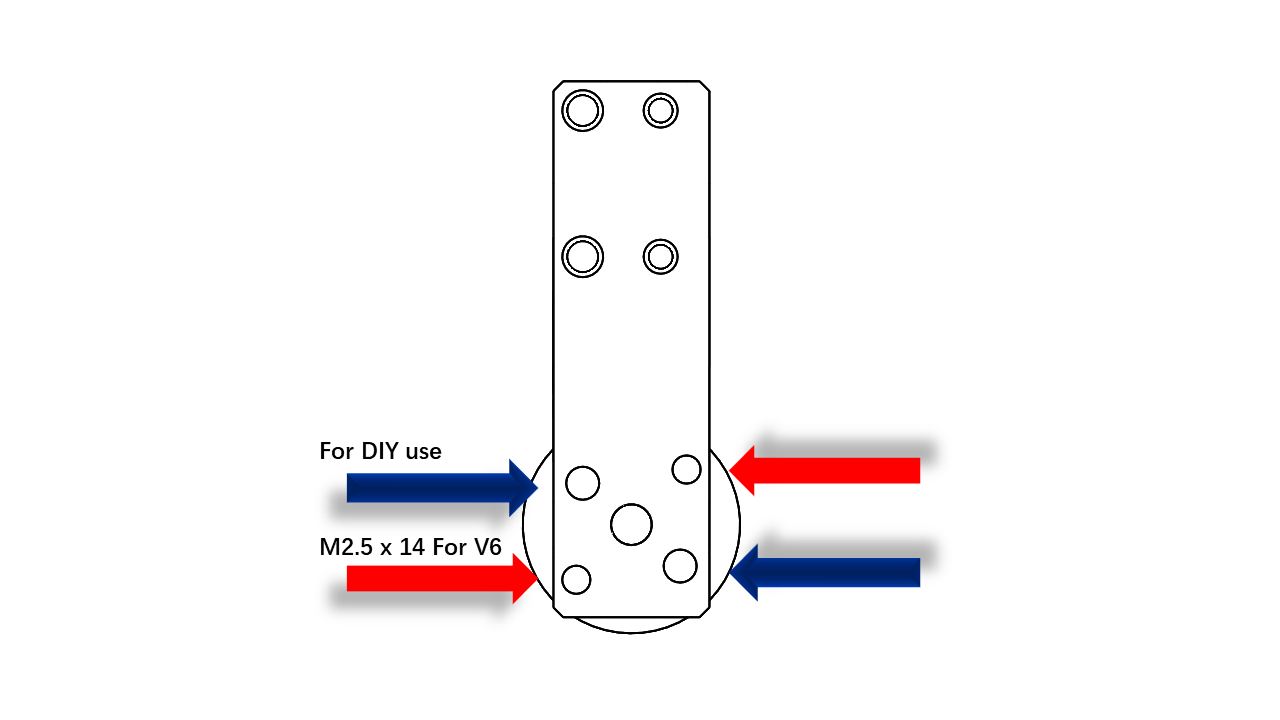
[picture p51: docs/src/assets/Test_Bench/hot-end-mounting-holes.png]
Hot-end mounting-hole options
    
    
4.  After installing the hot end, install the hot-end cooling fan as shown.
    
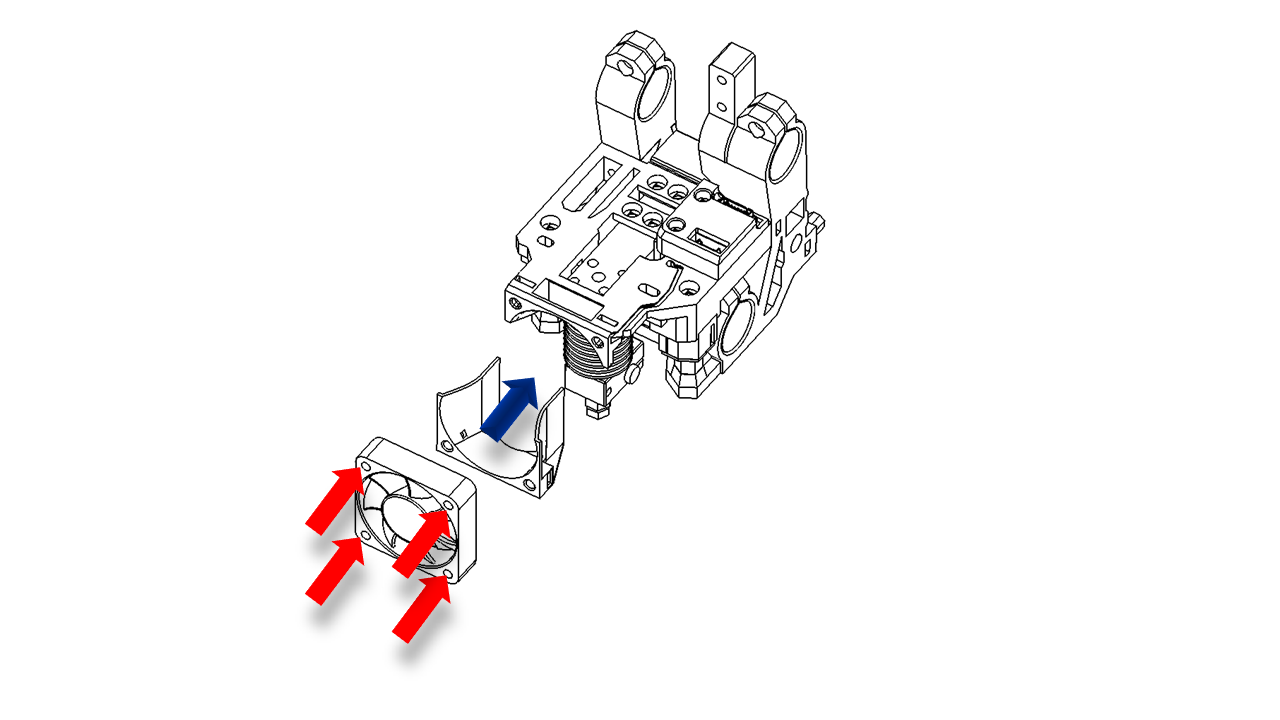
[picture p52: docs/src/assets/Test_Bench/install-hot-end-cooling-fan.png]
Install the hot-end cooling fan
    
    
5.  Complete the extruder installation. The P350 extruder is shown only as an installation example.
    
6.  Prepare a compatible 3D-printer controller board for the electrical bring-up. The controller board/mainboard is customer-supplied.
    
7.  Connect the ESP board and the Marlin-compatible controller board to your PC using USB cables.
    
8.  In Windows Device Manager, identify the COM ports assigned to the ESP board and controller board.

---

### 5. Firmware and Software Installation

1.  Prepare a customer-supplied Marlin-compatible 3D-printer controller board and flash the required Marlin firmware. Follow the controller-board manufacturer's instructions.
    
2.  Use a Marlin baud rate of 115200 unless your controller-board configuration specifies a different value.
    
3.  Configure the extruder correctly in Marlin and complete all required calibration and configuration steps.
    
4.  Download the complete portable test software package: [FSL Auto Test for Windows x64 (2026.08.17)](./src/assets/Test_Bench/FSL-Auto-Test-Windows-x64-2026.08.17.zip).
    
5.  Extract the complete ZIP file to a writable local folder. Keep `FSL Auto Test.exe` and the `_internal` folder together.
    
6.  Double-click `FSL Auto Test.exe` to start the test application. Python and the required libraries are included in the portable package.
    
7.  Make sure both USB connections are plugged in: one from the controller board and one from the ESP board.
    
8.  Identify the COM ports used by the controller board and ESP board. You can check them in Windows Device Manager.
    
9.  Select the correct ports in the test software. (Also the baud rate)

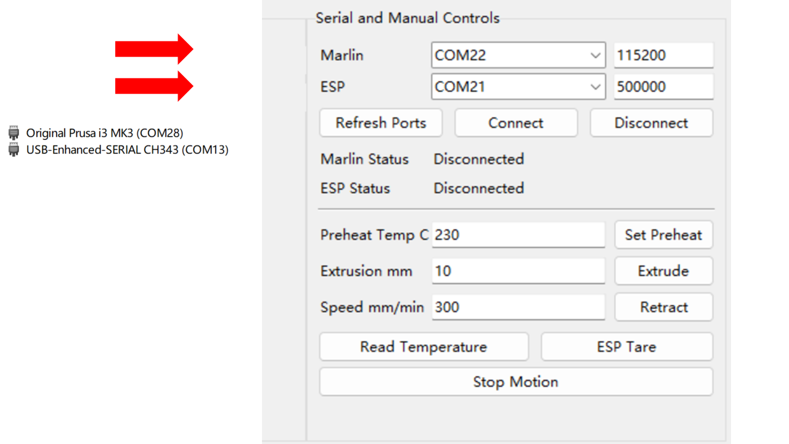
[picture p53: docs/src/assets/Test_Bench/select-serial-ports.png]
Select the Marlin and ESP serial ports
    
    
10.  Click **Connect** and wait for the connection to complete. When the connection is successful, the status indicator will update and temperature/PWM data should become available. You should see things like these.

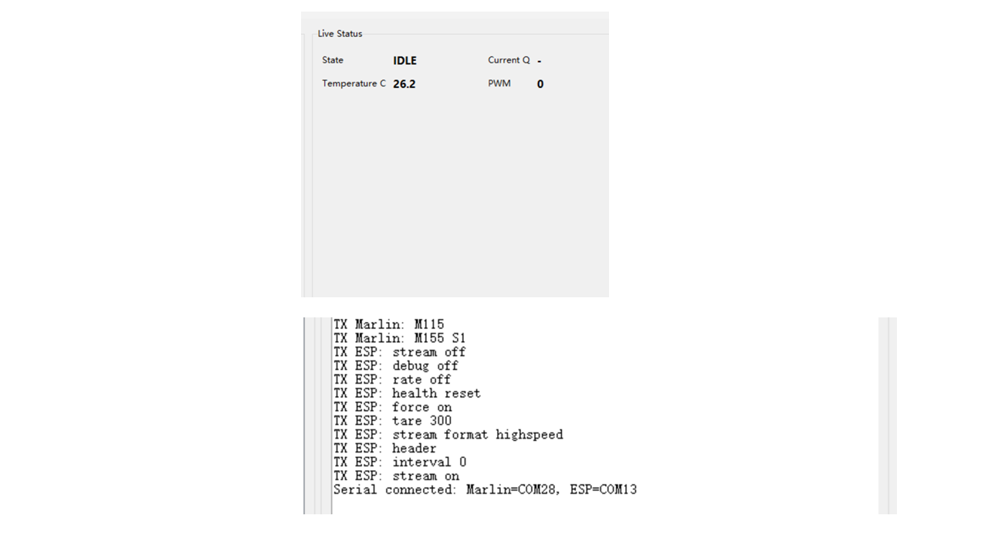
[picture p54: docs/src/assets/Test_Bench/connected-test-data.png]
Connected test data in FSL Auto Test
    
    
11.  If a connection error occurs, disconnect and reconnect both USB cables, then repeat the connection procedure.
    
12.  After communication is confirmed, continue to calibration.

---

### 6. Calibration

1.  Configure the extruder according to the documentation for your controller board and stepper driver. Confirm that the extruder-motor current, extrusion steps, and extrusion direction are correct.
    
2.  Perform the extrusion-length calibration before beginning the test-bench calibration procedure.
    
3.  Reference: [https://www.3dmakerengineering.com/blogs/3d-printing/estep-calibration](https://www.3dmakerengineering.com/blogs/3d-printing/estep-calibration)

---

### 7. Getting Help and Test Records

#### 7.1 When You Need Help

Record the following information before requesting support:

*   Test bench revision and serial number
    
*   Basic Tool Head revision and serial number
    
*   Firmware / configuration version
    
*   Exact failed step or test ID
    
*   Actual result and acceptance limit
    
*   Relevant photo or video
    
*   Relevant log or CSV file
    
*   Corrective action already attempted

**Support:** Visit the [Prorifi3D Upgrades GitHub repository](https://github.com/Prorifi3D-Official/Prorifi3D-Upgrades) to request support or report an issue.

---

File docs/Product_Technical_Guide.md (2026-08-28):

---
hide:
  - navigation
  - toc
---

# Product Technical Guide

- Here you can find technical details and guides about our products.

## Upgrade Kit for Original i3 MK3/MK3S/MK3S+

- [Stage1:XY Motor Upgrade](./stage1.md)

- [Stage2:XY Motor Upgrade + Structural optimization](./stage2.md)

- [Upgrade Kit for Original MINI/MINI+](./MINI.md)

## Motor Development Kit:

- [How to solve MRR](./How_to_solve_MRR.md)

## Prorifi3D P350 Kit:

- [P350 assemble Guide](./P350_kit_guide.md)

## Printer Test Bench:

- [Printer Test Bench Guide](./Test_Bench_Guide.md)

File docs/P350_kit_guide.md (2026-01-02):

---
hide: navigation
---

# P350 Kit

## 1. Preparation before Assembly

### 1.0 Introduction

<span style="color:red"> **READ THE INSTRUCTIONS BEFORE ASSEMBLY!!** </span> 

The P350 features a modular design and comprises the following main modules:

- Frame

- Zdrive

- Gantry

- Tool Head

- Heated Bed

- Enclosure(optional)

- Each can be pre-assembled separately.

- However, we recommend assembling in the following order:

- Frame, Zdrives, Gantry, Tool Head, Heated Bed,  Electronics.

## 2. Frame

### 2.0 Check before the assembly

#### 2.0.1 Printed parts 

- The printed parts required in this section contain:

- frame_down_left_front_corner (1pcs)

- frame_down_right_front_corner (1pcs)

- frame_down_left_rear_corner (1pcs)

- frame_down_right_rear_corner (1pcs)

- frame_up_left_front_corner (1pcs)

- frame_up_right_front_corner (1pcs)

- frame_up_left_rear_corner (1pcs)

- frame_up_right_rear_corner (1pcs)

- frame_rail_support (4pcs)

- Fixture: MGN12 fixtures (2pcs)

- Fixture: corner fixtures (4pcs)

- Metal Parts:

- T-Slot 3030 Aluminium Profile (12pcs in total)

- MGN12 450mm with MGN12H Blocks (4pcs) 

#### 2.0.2 Bolts and nuts

- The bolts and nuts required in this section contain:

- M8 x 16 Button Head Cap Screws (16pcs)

- M5x30  Screw (16pcs)

#### 2.0.3 Tools

- The tools required in this section contain:

- Hex(5mm)

- Hex(4mm)

#### 2.0.4 Workspace requirements

- The recommended working space needs to be as flat as possible. A minimum 2m x 1m space is recommended for placing the parts and tools

#### 2.0.5 Aluminium:

- Take out the extruded Aluminum from the Frame box carefully. 

### 2.1 Bottom Frame

#### 2.1.0 Assemble

- Note that the key to a good and correctly built frame is flatness and alignment.

- In this section, the flat surface you have and the printed part will work as fixtures. They will help you align the frame. 

- Here are the fixtures you will need:

- (pic)

- First, take and place the parts for the bottom frame as follows. Note that there are marks on the printed parts to indicate the orientation.

alt alternative text

alt alternative text

- Use the fixture to help you align the Aluminium profile. The boss on the fixture should fit nicely into the slots of the profiles.

alt alternative text

- Then put the M8 screws on. Tighten the screws against the table using the four corner fixtures.

alt alternative text

- Insert an M5x30 screw into the printed parts, and attach the T-nut (3030 M5).

alt alternative text

- For T-nut, you should always make sure it is turned 90 degrees correctly before tightening.

- You can check this **[video](https://youtu.be/_kZTA5S2jWY?si=gpDFgc6bVI7_g-RN)** to see how it is done.

alt alternative text

- A fully tightened T-nut should look like this.

alt alternative text

- Connect the printed part to the lower frame.Press the profile tightly against the desktop to tighten the corner printed parts, then loosen the M8 screws by about 90 degrees and pull out the fixture. Repeat this for all four corners. 

- Remember to remove the fixture before you proceed to the next step.

alt alternative text

- Slide the vertical frame into the corner we just assembled. You should align the bottom frame with the profile end surface with a level table surface.

- Then tighten the M8 screws. Note that you should tighten both screws in turn to ensure stress distribution.

- Repeate this for all four corners.

alt alternative text

#### 2.1.1 Check
- Once you are done, push the bottom frame against your flat working space. It should not bump or make noises when you apply force to each corner. 

### 2.2 Upper Frame
#### 2.2.0 Assemble
- First, take and place the parts for the upper frame as follows. Note that there are marks on the printed parts to indicate the orientation.
 
alt alternative text

- Use the fixture to help you align the Aluminium profile. The steps should fit nicely into the slots of the profiles.
alt alternative text

- Then put the M8 screws on. Tighten the screws against the table using the four corner fixtures.
 alt alternative text
 
- Insert an M5x30 screw into the printed parts, and attach the T-nut (3030 M5).
  alt alternative text

- Connect the printed part to the upper frame. For T-nut, you should always make sure it is turned 90 degrees correctly before tightening.

- Connect the printed part to the lower frame. Press the profile tightly against the desktop to tighten the corner printed parts, then loosen the M8 screws by about 90 degrees and pull out the fixture. 

 alt alternative text

- Repeat this for all four corners. 

- Remember to remove the fixture before you proceed to the next step.

#### 2.2.1 Check
- Make sure the upper frame sit steady on the flat surface.

- Slide the vertical frame into the corner we just assembled. You should align the bottom frame with the profile end surface with a level table surface.
Then tighten the M8 screws. Note that you should tighten both screws in turn to ensure stress distribution.
- Repeate this for all four corners.

### 2.3 Frame Assembly
#### 2.3.0 Main Frame
- Now, put the lower frame with vertial beam upside down. 

- Slide the vertical beam into the four corners of the upper frame. Once you are done, the frame should fit nicely.
 alt alternative text

- Now tighten the M8 screws in turn, making sure each screw applies relatively the same torque.

#### 2.3.1 Check
- Now check the frame. All the screws must be fully tightened. Put the frame in its initial orientation. Apply force on each corner of the upper frame against the flat surface as shown
. 
- The frame should not have any significant bumps or make any noise. Note that the profile straightness and torsion issues can cause slight unevenness. This is fine.

 alt alternative text

#### 2.3.2 Linear Rails
- Linear rails for the Z axis are very important for a 3D printer. We will use jigs and printed parts to ensure the alignment.
- First, attach the M3x10 screw and T-nut to the rail support. This part can determine the position of the rails. 

 alt alternative text

- Attach the rail support against the bottom of the frame as shown. Make sure the lower surface is directly against the bottom profiles.

 alt alternative text

- Note that the rail support should be attached to these locations.

 alt alternative text

- Now attach the M3x10 screws and T-nuts (3030 M3) on the rail as shown in the picture. Leave one empty and one placed. If the block or rubber insert blocks your operation. Slide them away and reinsert the rubber blocks at the end of the rail. 

- **Do not let the MGN12 Block drop out!**

 alt alternative text

- To install the linear rail, you will need the printed fixture. Get them in advance.

- Now, put the rail against the frame as shown and use both of the printed tools to clamp the rail on the frame for alignment.

 alt alternative text

- Tighten the M3 screws in turn. Note that these are T-Nuts. For T-nut, you should always make sure it is turned 90 degrees correctly before tightening.
You can check this **[video](https://youtu.be/_kZTA5S2jWY?si=gpDFgc6bVI7_g-RN)** to see how it is done.

### 2.4 Z-Drive
#### 2.4.0 Pre-insert the nuts
- Attach the M3 hex nuts to the screws and push the nuts until they reach the end. Do this for all Z-drive printed parts. Note that each Z-drive module has a mark on it. They are in pairs, so make sure we do not mix them.
 alt alternative text

 Insert the M5 nut and then use the **screw-pulling technique**. Screwed the nut in tightly to embed and then remove the screws
 alt alternative text

#### 2.4.1 Assembly 
- First, put the GT2-188mm timing belt on the largest wheel on the gear module.e
- Take the Z driver gear module and put it inside the slots. It should fit nicely. Note the orientation and then put the upper part as shown.
 alt alternative text

- Insert the long M3x50 screws as shown and tighten this module. Check if the GT-2 beltsares already on the gears. Tighten all screws properly. Rotate the gears inside. It should spin without any friction.
 alt alternative text
- Now it's time to attach the footpad. Use an M5 x 20 screw as shown.

 alt alternative text

Now we can prepare the motors. First, we need to insert **M3 nylon insert lock nuts** at the motor mount printed parts as shown. Attach the nut on the M3 screw first anduses it as a guide, then press the nut in with a 4mm hex tool. Remove the screw when you are done.

 alt alternative text

- Note that each motor mount is not the same. This mark shows the pairs it should have. This one, for example, can be matched with #0 or #2 Z-drivers.

- Now put the driving pulley on the motor. Use the jig to help you locate the correct position. 
 alt alternative text

Then you should attach the motor mount to the motor as shown with M3 x 8 and M3 x 16 screws. Note that the motor wires should be facing upwards.

alt alternative text

- The Z motors will be attached later. Do not install them at this point.

- Repeat this for all four Z-drives; be careful with the matching.

#### 2.4.2 Attach the Z-drive 
- Now, put the frame upside down,n as we are going to attach the Z-drive module.

- Pre-insert M5 spring nuts into the profiles at the bottom of the frame. You may use the Z-drive module as a jig to locate where these spring nuts should be.

 alt alternative text
- Fix the Z-drive module with M5 x 16 

 alt alternative text

Pass the Z belt as shown. Leaving enough length on both ends. 

 alt alternative text

## 3. Gantry 
### 3.1 The main Gantry
#### 3.1.0 Pre insert the nuts on printed parts
- All gantry parts have marks on them, which should match each other.

 alt alternative text

 - Insert M5 and M3 nuts on each of the gantry main parts (the four big ones)
 alt alternative text.

- There are bumps at the end of the M5 nut holes. This is to make sure the M5 nut stuck nice and tightly. For M5 nuts, use the screw pulling technique to make sure they reach the end. Once you are done, they should not fall out due to gravity. 

 alt alternative text.

- Do this for all four gantry main body parts. 

#### 3.1.1 Prepare the Z belts
- Take out the Z belts, put them aside for later use
#### 3.1.2 Prepare for assembly
- Find the 2020 profiles for the gantry; there are four of them. Place them as the picture shown. Make sure the marks match the locations. Note that the gantry has an asymmetrical design. 

 alt alternative text.

#### 3.1.3 Install the Y rails 
- First, attach the M3x8 screws and T-nuts to the rail as shown in the picture. Leave one empty and one placed. If the block or rubber insert blocks your operation. Slide them away and reinsert the rubber blocks at the end of the rail to prevent the block drop off. <span style="color:red">** Dropping out the sliding blocks may result a permenet damage to the linear rail!** <span>

 alt alternative text.

- Now place MGN9 rail guide jig at both ends to help you align the rail to the correct position.

 alt alternative text.

- Note that the rail should be centered, and it is slightly shorter than the profile. Neither end of the rail should stick out of the 2020 profile.

 alt alternative text.

- Tighten the T-nut properly. For T-nut, you should always make sure it is turned 90 degrees
correctly before tightening.
- You can check this **[video](https://youtu.be/_kZTA5S2jWY?si=gpDFgc6bVI7_g-RN)** to see how it is done.

- Do this for both 401mm profiles.

#### 3.1.4 Assemble the left part of the gantry (Part 1/0)
- First, we need to insert the spring nut.
- This isana M5 spring nut for 2020 profiles. Note that it is not symmetrical. Thus insert nuts can be a bit tricky.

 alt alternative text.

- You should insert the correct number of nuts on the profiles to secure them on the printed parts.
For 2 nuts, we recommend that you insert them as shown below.

 alt alternative text.

 - For the situation with 3 Nuts, you should replace the middle one with a regular T-nut. Otherwise, there is not enough space. 

 alt alternative text.

- The amount of nuts required is listed as shown. Follow the arrangement we have earlier.
Proceed after you have all the nuts inserted.

 alt alternative text.

 - Once you are done, insert the 2020 profilesinton these locations. Use a hex to help you locate nuts so they can align with the holes on the printed parts. 

 alt alternative text.

- Next, we need these printed parts labeled with 1/0

 alt alternative text.
 alt alternative text.

- Clip the Z belt to the bottom of Part 1. Note that the Z belt must match all slots on the parts. Use M5 x 14  to fix the bottom Z belt clip. Insert the M5 x 3050 Screw for later use.

 alt alternative text.

- Then install the upper part as shown. This M5 nut is for the M5 x 30 screw in the previous step.

 alt alternative text. 

 - Clip the Z belt to the bottom of Part 0. Note that the Z belt must match all slots on the parts. Use M5 x 14 to fix the bottom Z belt clip. Use M5 x 14 to fix the profile as shown.

 alt alternative text.

 - Use M5 x 14 to fix the upper part of the profile as shown. The most bottom scerw is M5 x 30.

 alt alternative text.

#### 3.1.5 Assemble the right part of the gantry (Part 2/3) 
- The amount of nuts required is listed as shown. Follow the arrangement we have earlier.
- Proceed after you have all the nuts inserted.

 alt alternative text.

 - Once you are done, insert the 2020 profiles into these locations. Use a hex to help you locate nuts so they can align with the holes on the printed parts. 
 alt alternative text.

- Next, we need these printed parts labeled with 2/3

 alt alternative text.
 alt alternative text.

- Clip the Z belt to the bottom of Part 2. Note that the Z belt must match all slots on the parts. Use M5 x 14 to fix the bottom Z belt clip and the profile. Insert the M5 x 38 screw for later use.

  alt alternative text.

- Use M3 x 35 to fix the printed part. Use M5 x 45 in the previous step to fix the pulley mount.
 alt alternative text.

- Use M5 x 14 and M5 x 30 to fix the belt clip and profile.  Note that the Z belt must match all slots on the parts. 
 alt alternative text.

#### 3.1.6 Install the gantry part

- As we finished the left and right parts of the gantry, it's now time to put them on the frame.
- Put them into the frame and pass the Z-belt through the Z drive as shown.

 alt alternative text.
 alt alternative text.

- Pass the Z-belt as shown. Do this for all Z belts.
 alt alternative text.

- Now take the Z rail mount for part 0. Note that the rail mount has a label on it. The labels must match.
 alt alternative text.

- Clip the Z-belt with the rail mount as shown, use M5 x 30 and M5 x 14 screw to tighten. The belt must match all slots on the gantry part. Once you are done, pull the belt to see if it's aligned.
 alt alternative text.

- For position 1, we need to first install the Z belt clip as shown. 

 alt alternative text.

- The rest is similar to the previous part. Note that the rail mount has a label on it. The labels must match.

 alt alternative text.

- Now take the Z rail mount for part 2. Note that the rail mount has a label on it. The labels must match.
- Clip the Z-belt with the rail mount as shown, use M5 x 30 and M5 x 14 screw to tighten. The belt must match all slots on the gantry part. Once you are done, pull the belt to see if it's aligned.

 alt alternative text.

 - Perform the same procedure for Part 3

 alt alternative text.

 - Now install the rail mount on the rail sliding block using M3 x 14 screws.

alt alternative text.
alt alternative text.
alt alternative text.
alt alternative text.

- Pre insert an M3 x 25 screw here.

alt alternative text.

- Insert an M3 nylon-locked nut here.

alt alternative text.

- Insert the pulley base, and slightly screw in the metal part of the nylon-locked nut.

alt alternative text.

- Pass the Z-belt to the pulley base as shown, use an M5 x 35 screw as the shaft.

alt alternative text.

- Insert the hex tool into the holes to guide the pulley and pass the Z belt as shown. Pull out the hex tool and tighten the screw.

alt alternative text.

alt alternative text

- Repeat these steps for all four pulley bases

#### 3.1.7 Install the 375mm profile
- Now take the shortest 2020 for the gantry. Pre-insert the spring nut and square nut as listed. 

alt alternative text.

- Insert the 375mm profile here as shown.

alt alternative text.

- Use an M5 x 14 screw to tighten it.

alt alternative text.

alt alternative text.

#### 3.1.8 Install the Rod mount.
- Pre-insert the nut on the rod mount as shown. 

alt alternative text.

- Take off the rubber block on the Y rail. Slice them to the back and install the two rod mounts as shown.

alt alternative text.
alt alternative text.
alt alternative text.
alt alternative text.

- Insert the two carbon rods as shown. Tighten the screws. Slide them to the front. If you feel too much friction. Untighten the screws on the 0/3 rail mount to release the stress in the system. Then tighten them. Slide the rods again, and you should feel no friction.

alt alternative text.
alt alternative text.

#### 3.1.9 Install the front beam.
- Take the 424mm profile, which is the longest, pre insert all nuts as shown.

 alt alternative text.

- Install the front beam with M5 screws as shown. 

 alt alternative text.

- Note that there is one decoration part.

alt alternative text.

- Slide the Y axis back and forth to make sure there is no extra friction. If there is, release the M5 x 14 on the front beam, slide the Y axis to the very front, and tighten the front beam. 

alt alternative text.

#### 3.1.10 Install Z motors.
- Now we can install the Z motors. Insert the motors as shown. Note that there are labels on the motor mount; you should make sure they match the positions you are operating.

alt alternative text.

alt alternative text.

- Now insert an M3 x 20 screw at these locations.

alt alternative text.

- Fully tighten the screw to make sure the motor belt is reaching the ideal tension. There should be no gaps here.

## 4. Tool Head

### 4.1 Assemble

#### 4.1.1 Hot end
- Take the hot end module and install it from below. Note the orientation.

alt alternative text.

- The hot end is mounted with one pair of diagonally placed screws. For default V6 use M2.5x14. Make sure you tightened them properly. 

alt alternative text.

- The hot end wires should come out from the gap here.

alt alternative text.

#### 4.1.2 Prepare the Fans 
- First, we need to pre-insert nuts in the wind tunnels.

alt alternative text.
alt alternative text.

- Now we need to prepare the blower fan. Take out the 5050 fan cover. There are two clips on the fan. It should come off without too much trouble.

alt alternative text.

- Now insert the rest of the 5050 fan into the printed parts as shown. 

alt alternative text.

#### 4.1.4 Prepare the belts
- Pre-insert the M3 nylon nut here before we install the fan.

alt alternative text.

- Pre-insert the timing belt here.

alt alternative text.

- Then slide in the left belt support as shown.

alt alternative text.

- Tighten the structure using M3 x 45. The belt should point out as shown.

alt alternative text.

alt alternative text.

- The other belt requires an extra belt support. Insert the GT2 belt as shown. The belt comes out of the mount as the blue arrow.

alt alternative text.

- The belt mount can be fitted in the slot of the tool head, as shown.

alt alternative text.

- Then slide in the belt support to fix the belt.

alt alternative text.

- Tighten the structure using M3 x 45. 

alt alternative text.

#### 4.1.5 Fan install

- Now it's time to install the heat sink fan. Place the part as shown and use M3 x 18 to tighten the fan. Note that the fan wires should come from the top of the fan.

alt alternative text.

- Take the blowing fan duct and mount it at the back. Attach them with M3 x 16 screws. Make sure the fan duct can slide up and down.
alt alternative text.

- There are two screws below; use M3 x 14 screws. Use a 5 mm washer if you use the default nozzle set (E3D V6), then tighten them to make sure the fan duct is at the correct location.  Once you are done, tighten the screws at the back to fully fix the fan duct.

alt alternative text.

#### 4.1.6 Final assembly
- Install the drag chain mount using M3 x14 screws.

alt alternative text.

#### 4.1.7 Extruder
- For P350, you can use some out-of-the-shelf extruders, such as [Sherpa Mini](https://github.com/Annex-Engineering/Sherpa_Mini-Extruder).

- Before we assemble the extruder, we need to prepare the printed parts and gears first.

- First, we need to put the extruder gear with set screws on the shaft. Tighten the set screw.

- Pre-insert M3 hex nut on printed parts at these locations.

alt alternative text.
alt alternative text.
alt alternative text.

- Put the ball bearing on the end with the large gears, and put the gear set into the slots as shown.        

alt alternative text.

- Assemble the printed parts as shown.

alt alternative text.

- Use M3 x 6 screws to fix the printed parts as shown.

alt alternative text.

- Press Insert the other gear with the shaft here. 

alt alternative text.

-  Insert the shaft and assemble the rest of the extruder as shown.

alt alternative text.

- Use the long M3 screws to fix the printed part.

alt alternative text.

- Put the spring on the nob and insert the nob as shown.

alt alternative text.

- Install the extruder motor as shown.

alt alternative text.

- Adjust the extruder motor to make sure the gears are meshed properly.

alt alternative text.

- Insert PTFE tube here, note the tube have chamfered. The chamfer should point upwards.
- Install the extruder with an M3 x 15 screw as shown. Adjust the slider block to make sure the screws are aligned.

alt alternative text.

### 4.2 Attach the tool head 
#### 4.2.0 Assemble
- Now, release the screws on the X axis as shown and slide the carbon tube to the right.

alt alternative text.

#### 4.2.1 Attach the Tool head
- Slide the tool head on the carbon tube onthe  X axis. Tighten the screws.

alt alternative text.

- Slide the tool head left and right, making sure it moves smoothly.

alt alternative text.

### 4.3 XY Belts
#### 4.3.0 Assemble
- Pre-insert the bearings with the pin(4.95 x 20) at the following positions. You can use a hex key as a pin guide to help you align the bearings. 

alt alternative text.
alt alternative text.

- For the front bearings the things will be a little different. Find these printed parts and pre-insert the M3 nylon nut.

alt alternative text.
alt alternative text.

- Then use M3 x 50 screws to fix the bearings as shown. Note the orientation.

alt alternative text.
alt alternative text.

#### 4.3.1 Mount the motors
- First, take the AB motor and use a jig to mount the pulley in the correct place. Tighten the screw. Make sure you tighten all set screws.
alt alternative text.

- Assemble the motors use M3 x 8 screw as shown. Note the orientation, the wires should come towards the inside. (shown by the blue arrow)

alt alternative text.
alt alternative text.

#### 4.3.2 XY belt 
- Now, let us do the belts. Since we pre-insert the belts on the tool head, the rest will be pretty easy.

- Warp the belts as shown.

alt alternative text.
alt alternative text.

- Take the belt clip, insert the M3 nylon nut as shown. The belt should fully match the teeth on the clip.
alt alternative text.

- Insert the Belt clip as shown. Note the direction.
- Use an M3 x 60 screw to apply tension on the belt as shown. Do not over-tighten the belts.

alt alternative text.
alt alternative text.

#### 4.3.3 Wire guide assembly
- Pre insert Nylon nut on the hex slots and hang the T-nut (3030 M5) with M5 x 10 screws.

alt alternative text.

- Pre insert Nylon nut on the hex slots and hang the T-nut (2020 M3) with an M3 x 10 screw.

alt alternative text.

- Install the mount as shown, do not fully tighten them yet. We will adjust the position later.

alt alternative text.

- Install the chain mount as shown, do not fully tighten it yet. We will adjust the position later.

alt alternative text.

- Use M3 x 10 screws to fix the truck chain. The tool head has a place for the chain. Clip the chain on the tool head. The wire slot should be facing outwards.

alt alternative text.
alt alternative text.

- Insert M3 x 10 screws and hang the T-nut (2020 M3) on the motor wire covers.

alt alternative text.

- Install the motor wire cover, making sure the motor wires are fully hidden inside.

alt alternative text.

- Take the large chain, take off the last two sections, and install them in reverse. 

alt alternative text.

- Install the large chain as shown. Note that the reversely installed part should be mounted on the gantry.

alt alternative text.

#### 4.3.3 Wires
- The front fan wires should be pressed into the slot on the tool head, as shown.

alt alternative text.

- The turbo fan wire should go through the wire guide as shown.

alt alternative text.

- All wires on the tool head should fit in the chain. Use a zip tie to make sure the wires do not fall out during movements. 

- Sort the wires and pass them through the large chain. These wires should pass through the square hole on the bottom plate.

alt alternative text.

- Sort all the wires and cover them as shown. This wire cover can be clip on the wire guide mount directly.

alt alternative text.

#### 4.3.4 Check

Move the tool head in X and Y full range to make sure the wire guide is ok.
Move the Z axis up and down to make sure the wire guide does not jam or having sudden move.

## 5. Heated Bed

### 5.1 Assemble the structural support
- Prepare the profiles. Use M5 x 16 screws to fix the corner fix on the profiles as shown. Do this for both 506mm 2020 profiles. 
- Then insert the M5 x 10 screw and hang the T-nut (3030 M5) for later use.

alt alternative text.

- Put the bottom plate on the frame. It should fit nicely.

alt alternative text.

- Fix the 2020 profiles on the bottom frame. You should use jigs to help you find the correct locations. Do not fully tighten the screws yet, as we may do some adjustments later.

alt alternative text.

- Pre-insert the 2020 M3 spring nut into the 2020 frame for later use.

alt alternative text.

### 5.2 Prepare the heated bed
- Now it is time to prepare the heated bed.

- Stick the heating element on the aluminium heated bed. Note the orientation. Make sure it is in the center of the heated bed.

- Stick the magnetic plate on the heated bed as shown. Note the orientation. The holes should match the ones on the aluminium plate.

alt alternative text.
alt alternative text.

- Put all wires of the heated bed through the round hole on the bottom plate as shown.

alt alternative text.

- Use M3 screws to fix the heated bed. Note that the heated bed is supported by these M4 nuts. Slightly tighten the screws.

alt alternative text.

- Adjust the position of the heated bed with jigs. Tighten all the screws.

- Put the spring steel sheet on the heated bed. 

### 5.3 Check
- Use the jig to check if the bed is in position. Once you are done, make sure the heated bed is fixed and can not move. 

## 6. Electronics

### 6.1 Prepare the wires
- Note that wires are color-coded with the IEC 60446 standard. 

- For high-voltage wires:
- The **<span style="color:brown">Brown</span>** wires are **<span style="color:brown">Live</span>** wires
- The **<span style="color:blue">Blue</span>** wires are **<span style="color:blue">Neutral</span>** wires
- The **<span style="color:yellow">Yellow</span>**-**<span style="color:green">Green</span>** wires are **<span style="color:yellow">Gro</span>****<span style="color:green">und</span>** wires.

- For low voltage part:
- **<span style="color:red">Red</span>** wires are **<span style="color:red">positive</span>**.
- **Black** wires are **negative**.

- For signal wires:
- Note these wires are fragile; operate with caution.

### 6.2 Assemble the power socket

- Pre-insert the short wires in the power socket as shown(Double arrow). Note the color coding. Then install the long wires (Single arrow pointing outwards).

alt alternative text.

- Insert the M3x12 screws and then hang the T-nut (3030 M3) on the printed parts.

alt alternative text.

- Insert the power socket into the printed parts as shown. Pass the wires through the printed part for later use.

alt alternative text.

- Fix the power socket on the frame as shown. The power socket should be pushed against the right rear z motor modules.

alt alternative text.

### 6.3 The electronics
- Now it is time to do the electronics. First, we flip the printer, let the front face upwards.
- Note the round hole location.

alt alternative text.

#### 6.3.0 Install the printed parts
- First, we need to install the support for electronics. Use M3x12 screws and hang the T-nut (2020 M3) on these printed parts. The bottom-most screw should be M3x18.

alt alternative text.

#### 6.3.0 Install the printed parts
- First, we need to install the support for electronics. Use M3x12 screws and hang the T-nut (2020 M3) on these printed parts. The bottom-most screw should be M3x18.

alt alternative text.

- Install the Control board support, Pi4 support, and ESP32 support in these locations as shown. Do not fully tighten the screws yet.

alt alternative text.

- Now take the power mount and the SSR mount. Use M3x18 screws and hang the T-nut (2020 M3) on these printed parts. The SSR module should also be included. Note that the 24V side must be facing upward.
alt alternative text.

- Use an M3x12 screw and hang the T-nut (2020 M3). Note the side screw should hangthe  T-nut(3030 M3)

alt alternative text.

- Then install the power mount as shown. Note that the printed part also acts as a jig; it should be directly against each other. The power mount should be against the bottom profile. Tighten the screw on the power relay to fix the printed part.
alt alternative text.

#### 6.3.1 Prepare the control board

- Before we mount the control board on the printer. We will need to install the motor driver first. In this kit, we use Fly-D8, which has the following config. 

alt alternative text.

- Since we usethe  TMC2209 driver, we will use the UART mode. Put jumpers on these locations with green marks first.

alt alternative text.

- Then, for X and Y motor,s we need sensorless homing. So we need to install jumpers on these Orange locations.

alt alternative text.

- Check the jumpers before you install the driver.

- Then we need to put the jumpers for the fans. We use only 24V fans, so we put jumpers at these locations marked with red marks.

alt alternative text.

- Then we can now prepare the TMC2209 drivers. There are 7 of them
- Stick the heat sink on the TMC2209 first

alt alternative text.

- Note the orientation. Install the drivers at the locations as shown. The leftmost socket is empty. Note the pin orientation. All pins on the driver should be connected.
alt alternative text.

#### 6.3.2 Mount the control board

- Install the control board on the printed support using M3x6 screws. It should fit just right. If not, slightly loosen the screws and adjust the support.

alt alternative text.

#### 6.3.3 Prepare the Pi4
- Raspberry Pi 4 is a powerful platform for all sorts of applications. In our kit, it serves as the Klipper Host.
- The powerful processing capabilities of the Pi4 also enable us to add many other features to the machine in the future.

- Due to the high performance, it is important to install the heat sink on Pi4. The kit contains ready-to-work heat sinks; we only need the upper half(the side with sockets)
- Connect the FPC/FFC as shown. Note the orientation, the blue stripe should face out of the board.

alt alternative text.

- Take the Heat sink for Pi and pass the FPC/FFC wires through the notch.

- Take the Pi mounting support and install the M3x10 screw in these locations. 

alt alternative text.

#### 6.3.4 Install the Pi4
- Use M3x10 screws to install Pi4 here.

alt alternative text.

#### 6.3.5 Install the ESP32
- Use M3x6 screws to install the ESP32. Note that the other two holes are reserved for later use.

alt alternative text.

#### 6.3.6 Install the power module
- The power module should be clamped by the two screws as shown. There are notches on the power module that will just fit these two screws, as shown.

alt alternative text.

### 6.4 Assemble the screen

- Connect the screen wire. 

alt alternative text.

- Take the screen cover and insert the 5 inch LCD screen. Note the screen has buttons; they should fit the printed press buttons. Then take the back panel and cover the screen. 

alt alternative text.

- Use M2 x 6 screws to fix the back panel.

alt alternative text.

- Use an M5 x 25 screw as a pivot, and use an M5 nylon nut on the other side to fix the screw.
- Do not fully tighten the screw. Make sure you can move the screen mount. 
- Insert M5 x 10 screws in the screen mount and hang the T-nut (M5 3030).

alt alternative text.

- Fix the screen mount on the bottom frame as shown. Adjust the screen so that it is in the middle.

alt alternative text.

### 6.5 Wiring
- For P350, we use Fly-D8 as the control board. You can check their official website if you need to **[DIY](https://mellow.klipper.cn/docs/ProductDoc/MainBoard/fly-d/fly-d8-f407/wiring/)**

- For our kit, please follow the instructions below:

#### 6.5.0 Z Motor wires

- Connect motor wires on Z motors. Note that we will need to connect the Z motors in order.

alt alternative text.

#### 6.5.1 Heated Bed wires
- Collect the heated bed wires we inserted in section 4. Connect the Heated bed wires as shown

alt alternative text.

#### 6.5.2 Tool head and Gantry wires
- Collect the tool head wires from the square hole and connect them as shown.

alt alternative text.

#### 6.5.3 Power wires
- Connect the power wires from the socket as shown. 

alt alternative text.

- Then connect the power wires as shown. 
alt alternative text.

#### 6.5.4 Pi4 wires
- Take a USB Type-C and connect to the location shown.

alt alternative text.

#### 6.5.5 ESP32 Wires
- Take the yellow-black wire. Connect the wire to the main board as shown.        

alt alternative text.

#### 6.5.6 Electronic cooling Fan wires

- Note that motor drivers require active cooling. So we have to install fans. Use M3x12 screws to install the 4010 fans (with short wires) on the Main cover as shown. Note the fan wires go upward.

alt alternative text.

- Connect these fans with a 3-in-1 adapter
- Connect the adapter as shown

alt alternative text.

#### 6.5.7 Check and sort the wires
- Please check the wire config and make sure it is correct. Especially the high voltage part!
- Then you should use ziptile to sort and fix the wires. There are many ziptile locations for you to use on the printed parts. They look like this:

alt alternative text.

#### 6.5.8 Install cover

- Install the power wire cover with M3x12 screws as shown; this should hide all high-voltage wires from the socket to the power module.

alt alternative text.

- Use M3x 16 screws and hang the T--Nut(3030 M3) on it.

alt alternative text.

- Install the power module cover as shown. Use M3x12 screws to fix the cover on the printed support.

alt alternative text.

- Install the ESP cover as shown. Use M3x12 screws

alt alternative text.

- Finally Install the Main cover with fans using M3x6 screws. The main cover should fit the slots on the electronic support. The gap on top is for the screen wire.

alt alternative text.

- The final result should look like this.

alt alternative text.

## 7.Firmware

- Now we can flash the Firmware. 

### 7.1 The Pi4 

- Download the System image via the following link: ()

- Take the SD card and follow the instructions on the Raspberry Pi official website(link) and flash the System image we just downloaded.

### 7.2 The Fly-D8

- Download the System image via the following link: ()

- Follow the instructions via this link to flash the image to your SD card:[Link](https://mellow.klipper.cn/en/docs/category/d8-f407%E5%9B%BA%E4%BB%B6%E7%BC%96%E8%AF%91%E4%B8%8E%E7%83%A7%E5%BD%95/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)

### 7.3 Printer configuration

- We recommend you copy and paste the default printer configuration first. To get the configuration, please click here: (git链接)

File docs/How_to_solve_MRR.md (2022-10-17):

---
hide:
  - navigation
---
<center><iframe width="560" height="315" src="https://www.youtube.com/embed/-et5eMyLlUs" title="YouTube video player" frameborder="0" allow="accelerometer; autoplay; clipboard-write; encrypted-media; gyroscope; picture-in-picture" allowfullscreen></iframe>
</center>

<span style="font-weight:lighter;font-size:28pt;">What is MRR/VFA? How to distinguish and test MRR?</span>

Unlike Ringing and other artifacts in 3D printing, MRR is usually shown as vertical ripples all over the vertical print surface. This is also why it is commonly known as Vertical Fine Artifacts (VFA). There are two types of "VFA": one with 0.6mm-0.8mm separation and the other one with 2mm separation The 2mm separation "VFA" is not MRR. It is caused by the polygon effect from the timing belt.

Both of the VFAs we talked about above are affected by speed. So printing a well-designed speed tower is an ideal way to test the situation.

# How to solve MRR

## 1. The source of the problem: Motors

- Motors are the root cause of MRR problems which is the source of vibration.So replacing the motors with low-vibration ones can effectively reduce MRR.

**Why not use 0.9° stepper motors?**

- This is because, compared with 1.8° stepper motors with similar electrical parameters, the 0.9° stepper motor has a significantly lower torque, maximum speed, and performance. This means they are only suitable for 3D printers with low performance.

## 2. Adjust the belt to an ideal tension

- Over tightening the belt can make MRR worse, However, untightening too much will result in the polygon effect which causes the 2mm VFA. So adjusting the belt to an ideal tension is necessary to improve the print quality.

## 3. Change the natural frequency of the motion system

- You can achieve this by optimizing the design, changing the length, width, and structure of the timing belt. Or you can optimize the frame design. A stronger and harder frame has a much higher natural frequency, allowing a higher MRR free printing speed.

## 4. Avoid the resonance frequency

- Using a much slower printing speed. This makes sure your printing speed is always below the MRR terrible speed ranges. Doing this may lose a lot of efficiencies but can reduce some MRR.

## 5. Extra tips: Driver settings

**The driver settings are very important! **

- If the current is too low, the motors will generate extra vibrations. When running with a current far less than the rated current, the smoothness and performance of the motor will be greatly reduced. Thus tuning the current settings of your drivers according to the recommendation from the manufacturer is necessary.

- In addition, some advanced drives such as TMC need to be tuned carefully. Otherwise, the output current will be distorted and causing an artifact very similar to MRR.

## Some attempts that proved ineffective

### Motor damping mounts:

- MRR originates from the output of the motors while damping mounts are an attempt to damp the transmission of vibrations from the motor body to the frame. This in principle cannot mitigate MRR.

### Current damper:

- The current damper is designed for old low end stepper drivers which have poor and distorted current waveforms. They are not for advanced drivers. If you found the current damper is effective for your advanced stepper drivers(such as TMC), This means your driver settings are not ideal this will result in a seriously distorted output waveform.

### Keep “Optimize” the stepper driver settings:

- The ideal motor driver setting makes the motor phase current to be an almost perfect sin wave over the print speed range. However, MRR is generated by the motor itself. Even if the driver output is a perfect sin wave, motors that are not specialized for 3D printing still produce MRR. So further tuning the settings of stepper drivers which is already tuned does not help reduce MRR and is a waste of time.

### Closed-loop stepper motors:

- Compare to servo motors, closed loop stepper motors will only correct when there is a losing step or about to lose steps. They do not optimize the motor vibration when the motor is running normally. According to our test results, closed loop stepper motors do not help to mitigate MRR.

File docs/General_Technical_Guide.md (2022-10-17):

---
hide:
  - navigation
  - toc
---

# General Technical Guide

### Here you can find technical details about our findings and theories

- [How to solve MRR](How_to_solve_MRR.md)

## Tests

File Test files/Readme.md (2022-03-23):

### Test Settings(Recommended)
##### 0% infill
##### 1 layer of outer shell thickness
##### no top and bottom layers
##### Speed increased by 5mm/s for every 5mm layer height
##### The testing range is from 20mm/s to 40mm/s (both inclusive). 
##### Auto cooling off(Auto cooling will change the printing speed)
##### For other settings, use default

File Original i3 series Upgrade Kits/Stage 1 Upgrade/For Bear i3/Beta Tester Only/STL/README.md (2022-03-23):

# Difference in BetaTester version:

### Y-Belt-Idler-A.stl -> Bear-y-idler-mount.stl
### Y-Belt-Idler-B.stl -> Bear-y-idler-tensioner-Beta tester only.stl

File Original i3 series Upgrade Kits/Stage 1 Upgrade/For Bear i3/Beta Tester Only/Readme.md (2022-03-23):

# Do Not use unless you are a Beta Tester

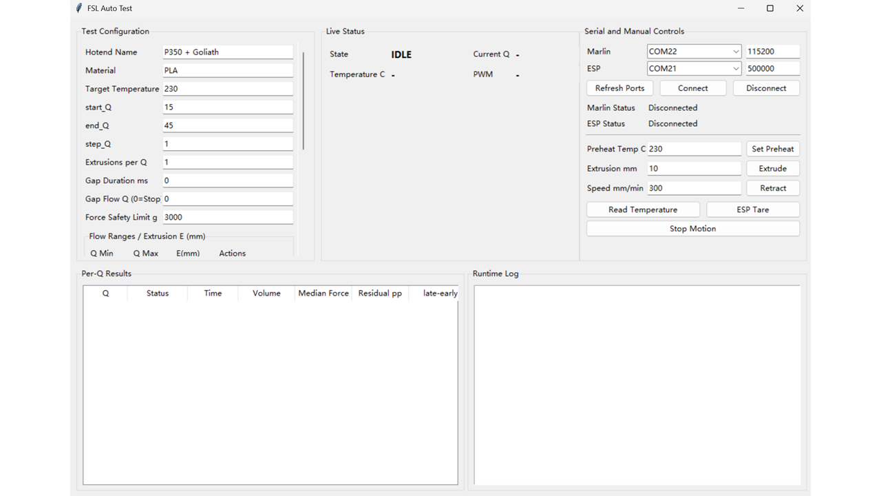
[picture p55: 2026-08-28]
docs/src/assets/Test_Bench/fsl-auto-test-interface.png

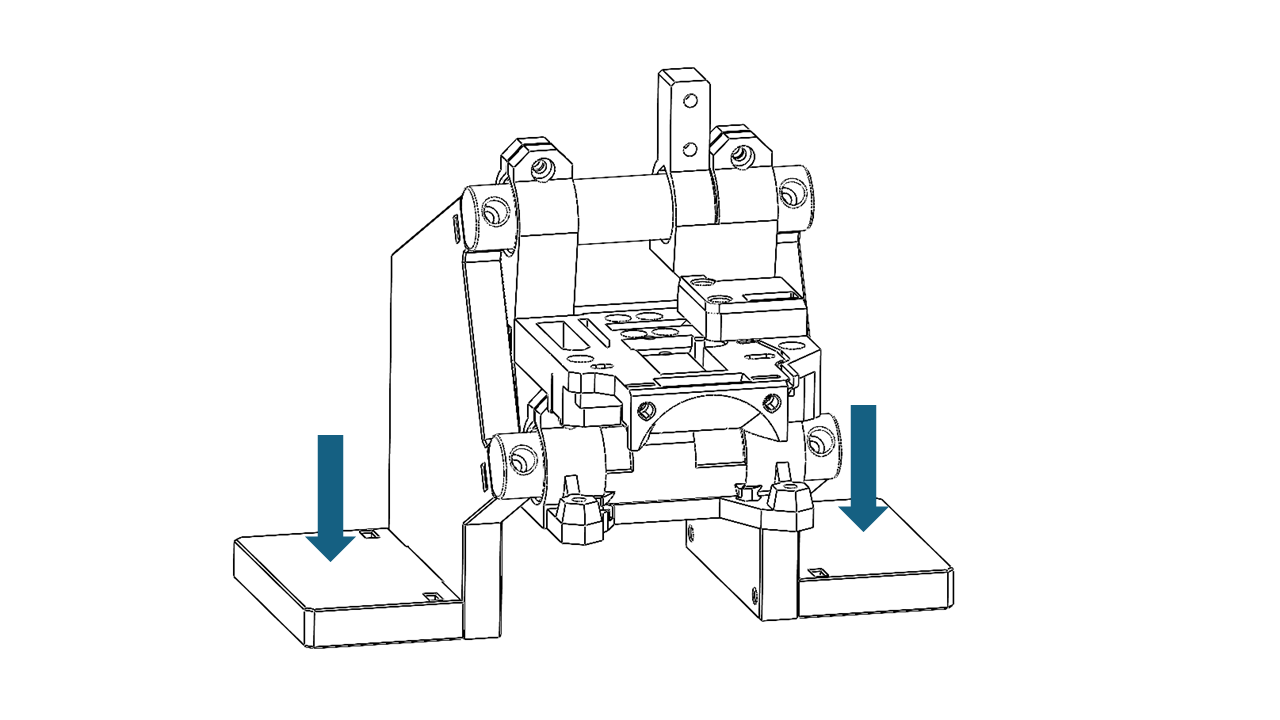
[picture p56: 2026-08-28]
tmp/site/src/assets/Test_Bench/press-down-bench-feet.png

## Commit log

2022-08-24 Upload step files for frame upgrade
2022-08-24 Re orgnized
    [(2)-Bottomcover.stl, (2)-PSU-Holder.stl, (4)-Endcover.stl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]
2026-08-28 Polish printer test bench guide
